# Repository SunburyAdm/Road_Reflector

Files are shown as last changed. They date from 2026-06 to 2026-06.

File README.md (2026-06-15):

# Smart Road Reflectors — Road Condition Monitoring & Data API Platform

Alpha Prototype of a Smart Road Reflector system that collects road condition
data, detects vehicle-related vibration events, transmits sensor data over a
LoRaWAN network, and exposes processed information through a cloud-based API,
dashboard, and 3D visualization.

## Repository Structure

```
.
├── docs/                     Project proposal, architecture, API, phases, budget
│
├── 01-device-layer/          Smart Road Reflector node
│   ├── firmware/             Production LoRaWAN firmware (RAK4631 / nRF52840)
│   ├── hardware/             Hardware design, recommended stack, placement
│   └── prototype-esp32c3/    Current ESP32-C3 bench prototype (sensor validation)
│
├── 02-connectivity-layer/    LoRaWAN network + outdoor gateway
│   ├── lorawan/
│   └── gateway/
│
├── 03-cloud-platform/        Ingestion, processing, storage, analytics
│   ├── chirpstack/           LoRaWAN Network Server
│   ├── mqtt-broker/          Mosquitto MQTT
│   ├── backend-fastapi/      FastAPI services
│   └── databases/            PostgreSQL + InfluxDB/TimescaleDB
│
├── 04-api-layer/             REST API, streaming API, auth, documentation
│
├── 05-data-consumers/        Visualization & consumer-facing layers
│   ├── web-dashboard/
│   ├── 3d-visualization/     Three.js
│   └── grafana/
│
└── tools/                    Helper scripts (live serial plotter, etc.)
```

## Documentation Index

| Document | Description |
|---|---|
| [docs/01-project-proposal.md](docs/01-project-proposal.md) | Full Alpha Prototype proposal |
| [docs/02-architecture.md](docs/02-architecture.md) | 5-layer system architecture |
| [docs/03-api-design.md](docs/03-api-design.md) | API groups, endpoints, payloads |
| [docs/04-development-phases.md](docs/04-development-phases.md) | Phases 1–7 and Alpha scope |
| [docs/05-budget.md](docs/05-budget.md) | Estimated prototype budget |

## Architecture Layers

```
1. Device Layer       → Smart Road Reflector nodes with embedded sensors
2. Connectivity Layer → LoRaWAN network and outdoor gateway
3. Cloud Platform     → Ingestion, processing, validation, storage, analytics
4. API Layer          → REST API, streaming API, authentication, docs
5. Data Consumers     → Dashboard, agencies, fleets, insurers, ADAS/OEM users
```

## Technology Stack

```
Device        : RAK4631 / nRF52840 + SX1262, ADXL362, SHT31, water/tilt/piezo, LiFePO₄ + solar
Connectivity  : LoRaWAN US915, RAK7289V2 / Milesight UG67 gateway
Network Server: ChirpStack
Messaging     : Mosquitto MQTT
Backend       : FastAPI
Databases     : PostgreSQL + InfluxDB / TimescaleDB
Dashboard     : Grafana + custom web dashboard
3D            : Three.js
Docs          : OpenAPI / Swagger
Security      : LoRaWAN OTAA, API keys, JWT, HTTPS
```

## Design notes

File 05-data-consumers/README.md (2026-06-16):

# 05 — Data Consumers

Visualization and consumer-facing layers.

## Structure

```
05-data-consumers/
├── web-dashboard/      Custom technical web dashboard
│   ├── index.html      Dashboard shell (KPIs, panels, 3D mount)
│   ├── css/dashboard.css
│   └── js/dashboard.js Hydration + live WebSocket controller
├── 3d-visualization/   Three.js real-time 3D road visualization
│   └── js/scene.js     SiteScene: builds site model, animates vehicles/pulses
└── grafana/            Grafana dashboards
```

> The dashboard and 3D scene are served by the FastAPI backend as static files at
> `http://localhost:8000/` (the dashboard imports `scene.js` from the sibling
> `3d-visualization/` folder). See [`../03-cloud-platform/DEMO.md`](../03-cloud-platform/DEMO.md)
> for the full run flow.

## Technical Dashboard

```
- Sensor location map
- Device online/offline status
- Battery level / solar charging status
- Pavement temperature / humidity / surface water
- Vibration levels / tilt or movement alerts
- Communication quality
- Historical trends
- Active alerts
- Exportable reports
```

## 3D Road Visualization (Three.js)

```
- Road segment model
- Smart reflectors installed on the road
- Real-time vehicle events
- Vehicle size approximation
- Vibration waves around sensors
- Road condition color indicators
- Live sensor values
- Alerts and event markers
```

Connected to the backend through WebSocket events (`WS /v1/stream/events`).

## Consumers

Government agencies, road maintenance companies, insurance companies, fleet and
logistics operators, universities and research labs, OEM / ADAS / autonomous
vehicle teams.

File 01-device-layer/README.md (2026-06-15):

# 01 — Device Layer

Smart Road Reflector node: embedded electronics, firmware, and hardware design.

## Structure

```
01-device-layer/
├── firmware/            Production LoRaWAN firmware (RAK4631 / nRF52840 + SX1262)
├── hardware/            Hardware design, recommended stack, bring-up notes
└── prototype-esp32c3/   Current ESP32-C3 bench prototype (sensor validation)
```

## Core Hardware Target

```
MCU + LoRaWAN : RAK4631 / nRF52840 + SX1262
Accelerometer : ADXL362 (low-power IMU)
Temp/Humidity : SHT31 + pavement temperature sensor
Other sensors : surface water sensor, tilt detection, optional piezo impact
Power         : LiFePO₄ battery + solar panel + solar charging + regulator
```

## Measured Signals

Vibration / acceleration, pavement temperature, internal humidity, surface
water presence, tilt / displacement, impact intensity, battery voltage, solar
charging voltage, communication signal quality.

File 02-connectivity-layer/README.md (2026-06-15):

# 02 — Connectivity Layer

LoRaWAN network and outdoor gateway configuration.

## Structure

```
02-connectivity-layer/
├── lorawan/   LoRaWAN US915 plan, OTAA keys policy, payload decoders
└── gateway/   Outdoor gateway configuration
```

## Recommended Setup

```
- LoRaWAN US915 frequency plan
- Outdoor LoRaWAN gateway
- Secure device registration
- OTAA device activation
- MQTT integration with backend services
```

## Gateway Options

```
Option A: RAK7289V2 Outdoor LoRaWAN Gateway
Option B: Milesight UG67 Outdoor LoRaWAN Gateway
```

The gateway receives data from multiple smart reflectors and forwards the
payloads to the cloud platform.

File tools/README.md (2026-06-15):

# Tools

Helper scripts for prototype development and sensor data analysis.

## Live serial plotter

```
python plot_sensors_live.py --port COM6 --baud 115200
```

Plots live sensor data streamed from the ESP32-C3 bench prototype.

> Prototype firmware: [`../01-device-layer/prototype-esp32c3/`](../01-device-layer/prototype-esp32c3/).

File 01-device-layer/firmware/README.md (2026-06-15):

# Firmware

Production firmware for the Smart Road Reflector node.

Target platform: **RAK4631 / nRF52840 + SX1262** with LoRaWAN US915 (OTAA).

## Planned responsibilities (Phase 4 / Phase 5)
- Sensor sampling (accelerometer, temperature, humidity, water, tilt)
- Vibration event detection
- Battery and solar charging monitoring
- LoRaWAN OTAA activation and uplink scheduling
- Compact telemetry payload encoding

> The current sensor-validation code runs on an ESP32-C3 bench prototype.
> See [`../prototype-esp32c3/`](../prototype-esp32c3/).

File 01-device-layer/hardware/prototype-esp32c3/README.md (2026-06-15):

# ESP32-C3 Bench Prototype

Current sensor-validation prototype running on an ESP32-C3. Used to validate the
thermistor (pavement temperature) and LIS3DH accelerometer (vibration) before
moving to the production RAK4631 / nRF52840 hardware.

## Sketches

| Folder | Description |
|---|---|
| `Road_Reflector/` | Main reflector sketch |
| `Road_Reflector_Temperature/` | Temperature-focused sketch |
| `thermistor_and_lis3dh_2/` | Thermistor + LIS3DH combined test (with serial debug reader) |

> Live serial plotting tooling lives in [`../../tools/`](../../tools/).

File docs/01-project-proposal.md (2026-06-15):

# Smart Road Reflectors — Road Condition Monitoring & Data API Platform

## Alpha Prototype Project Proposal

## 1. Project Overview
The goal of this project is to develop an Alpha Prototype of a Smart Road Reflector system capable of collecting road condition data, detecting vehicle-related vibration events, transmitting sensor data through a low-power wireless network, and exposing the processed information through a cloud-based API and dashboard.

The system will be designed as an infrastructure intelligence platform for roads, highways, industrial facilities, smart cities, insurance companies, logistics fleets, research institutions, and future autonomous vehicle ecosystems.

This prototype will not be a simple low-cost proof of concept. It will be built as a near-commercial demonstration platform with real sensor nodes, LoRaWAN communication, a gateway, backend services, API documentation, real-time visualization, and a dashboard.

---

## 2. Project Objective
The main objective is to create a functional Smart Road Reflector platform that can:

- Monitor vibration and acceleration from road traffic.
- Measure pavement temperature.
- Detect humidity or possible surface water.
- Monitor reflector movement, tilt, or displacement.
- Estimate vehicle events using multiple sensors.
- Approximate vehicle speed, direction, size class, and axle count.
- Send data through a LoRaWAN network.
- Store sensor and event data in a cloud platform.
- Provide a REST API and real-time streaming API.
- Display road condition data in a dashboard and 3D road visualization.

---

## 3. System Architecture
The proposed architecture is divided into five main layers:

```
1. Device Layer
   Smart Road Reflector nodes with embedded sensors

2. Connectivity Layer
   LoRaWAN network and outdoor gateway

3. Cloud Platform
   Data ingestion, processing, validation, storage, and analytics

4. API Layer
   REST API, streaming API, authentication, and documentation

5. Data Consumers
   Dashboard, government agencies, maintenance companies, fleets, insurers, universities, and ADAS/OEM users
```

See [02-architecture.md](02-architecture.md) for the detailed layer breakdown.

---

## 15. Estimated Prototype Budget
A realistic Alpha Prototype budget range is:

```
Estimated total hardware and infrastructure budget:
$2,500 to $8,000 USD
```

See [05-budget.md](05-budget.md) for the full breakdown.

---

## 16. Expected Outcome
At the end of the Alpha Prototype, the project should demonstrate a functional smart road intelligence platform capable of:

- Collecting sensor data from road-mounted reflectors
- Transmitting data through LoRaWAN
- Processing and storing road condition telemetry
- Detecting vehicle vibration events
- Estimating vehicle class and speed
- Displaying real-time sensor values
- Providing API access to external consumers
- Showing road and vehicle events in a 3D visualization

The prototype will be suitable for demonstrations with government agencies, road maintenance companies, insurance companies, fleet and logistics operators, universities and research labs, and OEM / ADAS / autonomous vehicle teams.

---

## 17. Final Project Definition
This project will create an Alpha Prototype of a Smart Road Reflector Road Condition Monitoring and Data API Platform.

The system combines embedded sensing, LoRaWAN communication, cloud processing, API services, and visualization tools to transform passive road reflectors into active infrastructure intelligence nodes.

The Alpha Prototype will validate the technical feasibility of using smart reflectors to monitor road conditions, detect vehicle events, estimate vehicle size classes, and provide real-time road data through a scalable API platform.

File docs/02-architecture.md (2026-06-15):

# System Architecture

The platform is divided into five main layers. Each layer maps to a top-level
folder in this repository.

| Layer | Folder | Responsibility |
|---|---|---|
| 1. Device Layer | [`01-device-layer/`](../01-device-layer/) | Smart Road Reflector nodes with embedded sensors |
| 2. Connectivity Layer | [`02-connectivity-layer/`](../02-connectivity-layer/) | LoRaWAN network and outdoor gateway |
| 3. Cloud Platform | [`03-cloud-platform/`](../03-cloud-platform/) | Ingestion, processing, validation, storage, analytics |
| 4. API Layer | [`04-api-layer/`](../04-api-layer/) | REST API, streaming API, authentication, documentation |
| 5. Data Consumers | [`05-data-consumers/`](../05-data-consumers/) | Dashboard, agencies, fleets, insurers, ADAS/OEM users |

---

## 4. Device Layer — Smart Road Reflector Node

### Core Hardware

```
MCU + LoRaWAN:
- RAK4631 / nRF52840 + SX1262 LoRa module

Main sensors:
- Low-power accelerometer / IMU
- Pavement temperature sensor
- Internal temperature and humidity sensor
- Surface water detection sensor
- Tilt / movement detection
- Optional piezo impact sensor

Power system:
- LiFePO₄ rechargeable battery
- Solar panel
- Solar charging circuit
- High-efficiency power regulator

Mechanical:
- Low-profile reflector enclosure
- Weather-resistant sealing
- Road-safe housing
- Replaceable or serviceable electronics module
```

### Sensor Capabilities

```
- Vibration / acceleration
- Pavement temperature
- Internal humidity
- Surface water presence
- Tilt or displacement
- Impact intensity
- Battery voltage
- Solar charging voltage
- Communication signal quality
```

---

## 5. Connectivity Layer

```
- LoRaWAN US915 frequency plan
- Outdoor LoRaWAN gateway
- Secure device registration
- OTAA device activation
- MQTT integration with backend services
```

### Gateway Options

```
Option A: RAK7289V2 Outdoor LoRaWAN Gateway
Option B: Milesight UG67 Outdoor LoRaWAN Gateway
```

---

## 6. Cloud Platform — Recommended Software Stack

```
LoRaWAN Network Server : ChirpStack
Message Broker         : Mosquitto MQTT
Backend API            : FastAPI
Relational Database    : PostgreSQL
Time-Series Database   : InfluxDB or TimescaleDB
Dashboard              : Grafana + custom web dashboard
3D Visualization       : Three.js
Documentation          : OpenAPI / Swagger
```

---

## 10. Vehicle Detection Method

Multiple reflectors installed along a lane estimate vehicle movement by
comparing vibration arrival times.

```
Traffic Direction →

S1 -------- 4 m -------- S2 -------- 4 m -------- S3
```

Estimated outputs: direction, approximate speed, event duration, approximate
vehicle length, number of vibration peaks, possible axle count, vehicle size class.

```
speed          = distance_between_sensors / time_difference
vehicle_length = estimated_speed × event_duration
```

---

## 12. Security and Reliability

```
Device Security        : Unique device ID, unique LoRaWAN keys, OTAA, signed firmware (future)
Communication Security : LoRaWAN encryption, HTTPS for API, MQTT authentication
API Security           : API keys, JWT for dashboard, rate limiting, request logging
Platform Reliability   : DB backups, gateway monitoring, device health, cloud logs, offline alerts
```

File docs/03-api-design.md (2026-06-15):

# API Design

## 7. API Layer

The API layer exposes sensor values, road condition data, vehicle events,
alerts, and device status.

### Main API Groups

```
Device API
Telemetry API
Road Condition API
Vehicle Event API
Alert API
Streaming API
```

### Example API Endpoints

```
GET  /v1/devices
GET  /v1/devices/{device_id}
GET  /v1/devices/{device_id}/latest
GET  /v1/devices/{device_id}/readings

GET  /v1/segments
GET  /v1/segments/{segment_id}/condition
GET  /v1/segments/{segment_id}/traffic-summary

GET  /v1/vehicle-events
GET  /v1/vehicle-events/{event_id}

GET  /v1/alerts
GET  /v1/alerts/active

POST /v1/ingest/telemetry
POST /v1/ingest/vehicle-event

WS   /v1/stream/events
```

---

## 8. Example Sensor Telemetry Payload

```json
{
  "device_id": "SRR-OH-001",
  "timestamp": "2026-06-12T19:20:10.000Z",
  "battery_v": 3.42,
  "battery_pct": 78,
  "solar_v": 5.18,
  "pavement_temp_c": 31.4,
  "internal_temp_c": 29.8,
  "humidity_pct": 61.2,
  "surface_water": false,
  "tilt_deg": 1.3,
  "accel_rms": 0.084,
  "accel_peak_g": 0.36,
  "vibration_energy": 12.7,
  "rssi": -105,
  "snr": 7.4
}
```

---

## 9. Example Vehicle Event Payload

```json
{
  "vehicle_event_id": "VEH-000482",
  "segment_id": "OH-TEST-001",
  "lane": 1,
  "timestamp": "2026-06-12T19:20:11.240Z",
  "sensor_ids": [
    "SRR-OH-001",
    "SRR-OH-002",
    "SRR-OH-003"
  ],
  "estimated_speed_kmh": 72.4,
  "estimated_length_m": 4.9,
  "estimated_axles": 2,
  "vehicle_class": "large_vehicle",
  "confidence": 0.84
}
```

### Initial Vehicle Classes

```
- small_vehicle
- medium_vehicle
- large_vehicle
- heavy_vehicle
- unknown
```

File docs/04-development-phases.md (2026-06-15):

# Development Phases

## Phase 1 — System Design and Architecture
Deliverables:
```
- System architecture document
- Hardware block diagram
- API design
- Database schema
- Communication payload definition
- Dashboard wireframe
```
Estimated duration: 2 to 3 weeks

---

## Phase 2 — Cloud Platform and API Prototype
Deliverables:
```
- FastAPI backend
- PostgreSQL database
- InfluxDB or TimescaleDB integration
- MQTT broker
- OpenAPI documentation
- Simulated sensor data ingestion
- Basic REST API
- WebSocket event stream
```
Estimated duration: 3 to 5 weeks

---

## Phase 3 — Dashboard and 3D Visualization
Deliverables:
```
- Web dashboard
- Sensor map
- Device status panel
- Road condition charts
- Alert list
- 3D road visualization
- Real-time vehicle event display
```
Estimated duration: 4 to 6 weeks

---

## Phase 4 — Smart Reflector Hardware Prototype
Deliverables:
```
- Electronics design
- Sensor integration
- Power system prototype
- LoRaWAN firmware
- Battery monitoring
- Solar charging test
- Vibration event detection firmware
- Enclosure prototype
```
Estimated duration: 6 to 10 weeks

---

## Phase 5 — Gateway and LoRaWAN Integration
Deliverables:
```
- Outdoor gateway configuration
- ChirpStack setup
- Device registration
- LoRaWAN payload decoder
- MQTT integration
- End-to-end telemetry test
```
Estimated duration: 2 to 4 weeks

---

## Phase 6 — Controlled Road Test
Deliverables:
```
- Installation of 6 smart reflector nodes
- Controlled vehicle pass tests
- Sensor calibration
- Vehicle event dataset
- Speed and size estimation validation
- Battery and solar performance report
```
Estimated duration: 4 to 6 weeks

---

## Phase 7 — Alpha Demonstration Platform
Deliverables:
```
- Final Alpha dashboard
- API documentation portal
- Live road condition monitoring
- Real-time vehicle event visualization
- Demo dataset
- Technical report
- Investor/customer demo package
```
Estimated duration: 2 to 4 weeks

---

## 13. Alpha Prototype Scope

```
- 6 smart road reflector nodes
- 1 outdoor LoRaWAN gateway
- 1 cloud server
- LoRaWAN network server
- MQTT broker
- Backend API
- Time-series database
- Dashboard
- 3D visualization
- OpenAPI documentation
```

### Suggested Physical Deployment

```
Lane 1:  S1 ---- 4 m ---- S2 ---- 4 m ---- S3
Lane 2:  S4 ---- 4 m ---- S5 ---- 4 m ---- S6
```

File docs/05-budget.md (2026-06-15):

# Estimated Prototype Budget

A realistic Alpha Prototype budget range:

```
Estimated total hardware and infrastructure budget:
$2,500 to $8,000 USD
```

## Estimated Breakdown

| Item | Estimated Cost |
|---|---|
| 6 smart reflector prototypes | $600 to $1,800 |
| Outdoor LoRaWAN gateway | $400 to $900 |
| Solar, battery, enclosure, mechanical parts | $600 to $2,000 |
| PCB prototype and assembly | $500 to $2,000 |
| Cloud server and services | $30 to $250 per month |
| Testing materials and installation | $300 to $1,000 |

> This estimate does not include engineering labor, certification, final
> tooling, mass production, or legal/patent review.

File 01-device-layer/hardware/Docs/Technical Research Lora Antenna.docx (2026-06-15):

Technical Research: Near-Ground LoRa Antenna for a Smart Road Reflector

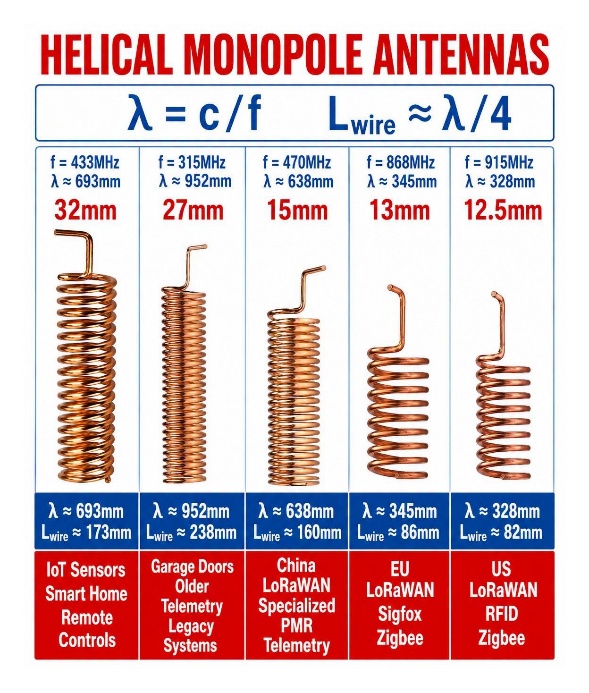
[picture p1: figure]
Puede ser una imagen de texto que dice "f= 433MHz እ= 693mm 32mm HELICAL MONOPOLE ANTENNAS እ=/ Lwire እ/4 470MHz f=868MHz f= እ= 638mm እ= 345mm 15mm 13mm f=315MHz እ= 952mm 27mm f=915MHz ለ= 328mm 12.5mm 12. እ 693mm Lwire 173mm ለ 952mm Lwire 238mm እ 638mm Lwire 160mm እ= 345mm Lwire 86mm loT Sensors Sma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

1. Executive Summary

Designing a LoRa antenna for a device installed almost flush with the ground is possible, but it is a difficult RF problem. A near-ground antenna will suffer from reduced efficiency, shorter communication range, detuning, signal absorption, and high sensitivity to moisture, snow, salt, vehicles, and pavement material.

The main conclusion is:

The best solution is not a completely flat antenna, but a low-profile antenna that appears flush from the outside while keeping a small vertical RF structure inside the reflector.

The recommended prototype design is:

915 MHz vertical helical antenna

Height: 25–35 mm

Diameter: 5–8 mm

Ground plane: 70–100 mm if the reflector body allows it

Matching network: π-network

Housing: sealed non-metallic plastic

Gateway: elevated, ideally 3–10 m or higher

For testing in Ohio / United States, the target LoRaWAN band should be US902–928 MHz, with a practical center frequency around 915 MHz.

2. Engineering Problem

The goal is to design a LoRa antenna for a road-installed device, likely inside a smart road reflector, with the following constraints:

- Very low physical profile

- Installed almost flush with the road surface

- Exposure to water, snow, salt, vibration, dust, and extreme temperature

- Low-power LoRa communication

- Low manufacturing cost

- Reliable range to other reflectors or gateways

- Possible mesh or relay communication architecture

The main issue is that the road environment is a poor RF environment. Pavement, soil, concrete, water, and nearby vehicles affect antenna behavior. They can detune the antenna, absorb energy, distort the radiation pattern, and reduce range.

Antenna performance near the ground is strongly affected by:

- Height above the ground

- Pavement material

- Moisture content

- Ground plane size

- Antenna orientation

- Vehicle obstruction

- Snow, salt, and ice

- Housing material

3. Target Frequency

For LoRa in the United States, the practical design target is:

Band: US902–928 MHz

Center frequency: approximately 915 MHz

Wavelength: approximately 328 mm

Quarter wavelength: approximately 82 mm

Calculation:

λ = c / f

c = 300,000,000 m/s

f = 915,000,000 Hz

λ = 0.328 m = 328 mm

λ/4 = 82 mm

This means that a physically efficient quarter-wave antenna at 915 MHz would be about 82 mm long.

Because a road reflector cannot realistically have an 82 mm vertical whip antenna, the antenna must be electrically shortened. Practical options include:

- Helical antenna

- PIFA antenna

- Inverted-F antenna

- PCB meander antenna

- Chip antenna

- Patch antenna

4. Antenna Options

Option A — Quarter-Wave Whip / Monopole Antenna

This is electrically one of the best options.

Physical length: ~82 mm

Ideal orientation: vertical

Ground plane: required

Cost: low

RF performance: high

Physical profile: poor for road installation

A quarter-wave monopole would give good range and simple tuning, but it is not mechanically suitable for a reflector installed close to the ground.

Conclusion: good for laboratory testing, not ideal for the final product.

Option B — Vertical Helical Antenna

A helical antenna is a coiled conductor that compresses the physical size of the antenna while maintaining useful electrical length.

Physical height: 20–40 mm

Diameter: 5–10 mm

Cost: low

RF performance: medium to good

Difficulty: medium

Physical profile: acceptable

This is the best balance for your application. The antenna can be placed inside a small raised section of the reflector, protected by plastic. Visually, the product can still appear low-profile, but electrically the antenna keeps a useful vertical component.

Conclusion: best option for the first prototype.

Option C — PIFA / Inverted-F Antenna

A PIFA, or Planar Inverted-F Antenna, is commonly used in compact wireless devices.

Physical height: 3–10 mm

Cost: low to medium

RF performance: medium

Difficulty: high

Requires good ground plane

Requires careful tuning

This is a good option if the industrial design cannot allow a 25–35 mm vertical antenna volume.

Conclusion: strong second option, but more difficult to design correctly.

Option D — PCB Meander Antenna

A PCB meander antenna is printed directly on the circuit board in a folded shape.

Physical height: PCB thickness only

Cost: very low

RF performance: low to medium

Difficulty: high

Very sensitive to housing and ground plane

This option is attractive because it is cheap and flat, but it is not ideal for a harsh road environment where the antenna is close to pavement, water, salt, and metal.

Conclusion: possible, but risky for long-range communication.

Option E — Chip Antenna

A chip antenna is a compact ceramic or RF component mounted on the PCB.

Size: very small

Cost: medium

RF performance: medium to low if not tuned properly

Difficulty: medium to high

Requires strict layout rules

Chip antennas are compact, but their performance depends heavily on PCB layout, ground plane, housing, and nearby components.

Conclusion: viable only if the manufacturer’s layout guidelines are followed and the final product is tuned with a VNA.

Option F — Patch Antenna Facing Upward

A patch antenna can radiate upward, which may be useful if the gateway is mounted above the road.

Profile: low

Radiation: directional upward

Cost: medium to high

Difficulty: high

Size at 915 MHz: relatively large

This could work well if communication is mainly between the reflector and an elevated gateway. It is less ideal for reflector-to-reflector communication.

Conclusion: interesting for gateway-based architecture, less ideal for mesh between reflectors.

5. Technical Comparison

Antenna Type | Physical Profile | Cost | Expected Range | RF Robustness | Recommendation
Quarter-wave whip | Poor | Low | High | High | Lab testing only
Vertical helical | Good | Low | Medium/high | Medium | Best option
PIFA | Very good | Medium | Medium | Medium | Strong alternative
PCB meander | Excellent | Very low | Low/medium | Low | Risky
Chip antenna | Excellent | Medium | Medium | Medium/low | Viable with tuning
Patch antenna | Good | Medium/high | Medium/high upward | Medium | Good for elevated gateway

6. Recommended Design

6.1 Physical Architecture

Non-metallic plastic cover

┌───────────────────────────────┐

│ 915 MHz helical antenna │

│ 25–35 mm high │

└──────────────┬────────────────┘

│

π matching network

│

LoRa module

│

PCB/base ground plane

│

Battery + sensors

│

Sealed road housing

6.2 Initial Prototype Specification

Target frequency: 915 MHz

Operating band: 902–928 MHz

Antenna type: loaded helical monopole

Physical height: 25–35 mm

Coil diameter: 5–8 mm

Approximate conductor length: 75–85 mm

Target impedance: 50 Ω

Target return loss: < -10 dB

Target VSWR: < 2:1

Minimum ground plane: 70 mm

Preferred ground plane: 100 mm or larger

Housing material: ABS, polycarbonate, nylon, or RF-friendly plastic

Avoid: metal, metallic paint, carbon fiber, screws near the antenna

7. Concept Diagram

Side View

Elevated Gateway

▲

│

│ LoRa link

│

┌────────┴────────┐

│ │

│ main RF │

│ radiation │

│ │

──────────────────────────────── road surface

┌───────────────────┐

│ smart reflector │

│ ┌─────┐ │

│ │coil │ │ ← vertical helical antenna

│ └──┬──┘ │

│ │ │

│ matching + RF │

│───────────────────│ ← ground plane

│ battery/sensors │

└───────────────────┘

8. Why a Completely Flat Antenna Is Not Recommended

A completely flat antenna installed at road level has three major problems.

8.1 Pavement Loss

Concrete, asphalt, wet soil, water, and road salt act as lossy dielectric materials. They can absorb RF energy and shift the antenna away from its tuned frequency.

8.2 Distorted Radiation Pattern

A near-ground antenna does not radiate cleanly. Energy can couple into the road surface, reflect unpredictably, or be blocked by vehicles.

8.3 Polarization Loss

Most LoRa gateways use vertically polarized antennas. If the reflector antenna is horizontal, the link can suffer additional polarization mismatch loss.

For this reason, even a small vertical antenna element is valuable.

9. Link Budget Considerations

LoRa has a strong link budget compared with many wireless technologies, but the road environment can consume a large part of that margin.

A simplified estimate:

TX power: up to +22 dBm, depending on module and regulatory limits

Receiver sensitivity: approximately -137 to -148 dBm depending on LoRa settings

Reflector antenna gain: possibly -5 to -15 dBi if very low-profile

Gateway antenna gain: +2 to +6 dBi

Housing / pavement / moisture losses: 3–15 dB or more

The system may still work because LoRa is robust, but range will depend heavily on:

- Gateway height

- Antenna height inside the reflector

- Pavement material

- Moisture, snow, and salt

- Vehicle obstruction

- Spreading factor

- Transmit power

- Antenna matching quality

- Ground plane size

In practice, increasing gateway height will likely improve performance more than simply increasing transmit power.

10. Regulatory Considerations

For the United States, LoRa operation around 902–928 MHz falls under FCC Part 15 rules. For a commercial product, this means:

- Use a compliant LoRa module or certify the final product.

- Do not assume any antenna can be used with a pre-certified module.

- Check the antenna types allowed by the module certification.

- Avoid high-gain antennas unless the transmit power is adjusted accordingly.

- Keep documentation of the final antenna, matching network, and enclosure.

For the reflector itself, a low-gain omnidirectional antenna is preferable.

11. Recommended Test Plan

Phase 1 — Bench Antenna Test

Goal: find an antenna that resonates correctly around 915 MHz.

Tools:

- VNA, such as NanoVNA V2 or better

- U.FL or SMA test connector

- Prototype ground plane

- Test housing or 3D-printed enclosure

Measurements:

- S11

- VSWR

- Resonant frequency

- Bandwidth

- Effect of housing

Minimum target:

Return loss < -10 dB across 902–928 MHz

VSWR < 2:1

Phase 2 — Reflector Integration Test

Measure the antenna under realistic conditions:

1. Reflector open

2. Reflector closed

3. Reflector on a table

4. Reflector on concrete

5. Reflector on asphalt

6. Reflector with water on top

7. Reflector with salt / ice exposure

8. Reflector near metal

The most important thing is to check frequency shift. If the antenna resonates at 915 MHz on the bench but shifts to 880 MHz or 950 MHz after being installed in the housing, the design is not ready.

Phase 3 — Field Test

Record the following variables:

- RSSI

- SNR

- Packet loss

- Spreading factor

- Distance

- Gateway height

- Reflector orientation

- Weather condition

- Vehicle presence

Suggested distances:

- 10 m

- 50 m

- 100 m

- 250 m

- 500 m

- 1 km

Critical tests:

- Gateway at 1 m height

- Gateway at 3 m height

- Gateway at 6 m height

- Gateway at 10 m height

Expected result:

A higher gateway will likely improve the link more than increasing the reflector transmit power.

12. Prototype Proposals

Prototype A — Vertical Helical Antenna

Type: 915 MHz helical antenna

Height: 30 mm

Diameter: 6 mm

Ground plane: 80–100 mm

Matching: π-network

Purpose: main prototype

Advantages:

Best balance of size, cost, and range.

Disadvantages:

Requires a small vertical RF chamber inside the reflector.

Prototype B — Internal PIFA

Type: PIFA / IFA

Height: 5–10 mm

Dedicated PCB region

Integrated ground plane

Mandatory matching

Purpose: flatter alternative

Advantages:

More compatible with a nearly flush mechanical design.

Disadvantages:

Harder to design and tune correctly.

Prototype C — PCB Meander Antenna

Type: printed PCB antenna

Height: PCB thickness only

Cost: very low

Purpose: minimum-profile experiment

Advantages:

Very low cost and very flat.

Disadvantages:

Likely shorter range and more sensitivity to the environment.

13. Final Recommendation

For a LoRa smart road reflector installed almost flush with the ground, the recommended technical solution is:

Use a 915 MHz vertical helical antenna,

sealed inside a non-metallic plastic cover,

with a dedicated ground plane,

a π matching network,

and an elevated gateway.

A completely flat antenna should only be used if the required range is short or if many gateways are installed nearby.

The best interpretation of “almost flush with the ground” is:

The product should look flush from the outside, but internally it should include a small 25–35 mm RF chamber for the antenna.

This design has the best chance of being robust, low-cost, manufacturable, and effective in real road conditions.

Investigación técnica: Antena LoRa prácticamente al ras del suelo para reflector vial inteligente

1. Resumen ejecutivo

Para un sistema de smart road reflectors con LoRa, la antena es uno de los puntos más críticos. Una antena colocada al ras del suelo puede funcionar, pero tendrá menor eficiencia, menor alcance y mayor variación de desempeño por humedad, nieve, sal, concreto, asfalto, vehículos y orientación.

La conclusión principal es:

La mejor solución no es una antena completamente plana, sino una antena de bajo perfil que se vea al ras visualmente, pero que mantenga una pequeña estructura vertical interna de 20–40 mm dentro del reflector.

La opción más recomendable para prototipo es:

Antena helicoidal vertical 915 MHz

Altura: 25–35 mm

Diámetro: 5–8 mm

Plano de tierra: 70–100 mm si el housing lo permite

Red de matching: π-network

Housing: plástico no metálico, sellado

Gateway: elevado, idealmente 3–10 m o más

Para Ohio / Estados Unidos, la banda LoRaWAN usada normalmente es US902–928 MHz. The Things Network resume esta banda como 902–928 MHz, con canales uplink de 902.3–914.9 MHz y downlink de 923.3–927.5 MHz. (The Things Network (https://www.thethingsnetwork.org/docs/lorawan/regional-parameters/us915/))

2. Problema de ingeniería

El objetivo es diseñar una antena LoRa para un dispositivo instalado en carretera, posiblemente dentro de un reflector vial, con estas restricciones:

- Muy bajo perfil físico.

- Instalación prácticamente al ras del suelo.

- Exposición a agua, nieve, sal, vibración, polvo y temperatura extrema.

- Comunicación LoRa de bajo consumo.

- Bajo costo de fabricación.

- Buen alcance hacia otros reflectores o gateways.

- Posible red mesh o comunicación hacia concentrador.

El problema principal es que la carretera es un mal entorno RF. El suelo modifica el patrón de radiación, cambia la impedancia de la antena y absorbe parte de la energía. En estudios recientes de antenas tipo monopolo cerca de suelo/humedad, se reportó que la altura del dispositivo y el contenido de agua del suelo afectan impedancia, ancho de banda, patrón de radiación y eficiencia; en el peor escenario, la eficiencia de radiación cayó hasta 44%. (MDPI (https://www.mdpi.com/2079-9292/14/3/544))

3. Frecuencia objetivo

Para Estados Unidos:

Banda: US902–928 MHz

Frecuencia central práctica: 915 MHz

Longitud de onda aproximada: 328 mm

Cuarto de onda: 82 mm

Cálculo:

λ = c / f

c = 300,000,000 m/s

f = 915,000,000 Hz

λ = 0.328 m = 328 mm

λ/4 = 82 mm

Esto significa que una antena eficiente de 1/4 de onda para 915 MHz tendría aproximadamente 82 mm de longitud eléctrica. Como el reflector vial no puede tener una varilla vertical de 82 mm, se necesita una antena compactada: helicoidal, PIFA, IFA, chip antenna o PCB meander.

4. Revisión de alternativas de antena

Opción A — Antena whip / monopolo de 1/4 de onda

Es la opción eléctricamente más simple y eficiente.

Longitud física: ~82 mm

Orientación ideal: vertical

Plano de tierra: necesario

Costo: bajo

Desempeño: alto

Perfil físico: malo para carretera

Semtech describe la antena externa de cuarto de onda como una de las mejores desde el punto de vista de sensibilidad y ganancia para 915 MHz, pero también indica que ocupa más espacio y aumenta costo por requerir conector externo.

Conclusión: buena para pruebas de laboratorio, mala para producto final al ras del suelo.

Opción B — Antena helicoidal vertical

Una antena helicoidal es básicamente una longitud de conductor enrollada. Permite reducir el tamaño físico manteniendo una longitud eléctrica útil. Semtech la presenta como una alternativa de bajo costo frente a chip antennas; también advierte que tiene ancho de banda estrecho y puede detunarse por objetos cercanos en el PCB.

Altura física: 20–40 mm

Diámetro: 5–10 mm

Costo: bajo

Desempeño: medio/bueno

Dificultad: media

Perfil físico: aceptable

Conclusión: es la opción más balanceada para tu caso.

Esta antena podría ir dentro de una pequeña zona elevada del reflector, sin que parezca una antena externa.

Opción C — PIFA / Inverted-F Antenna

La PIFA es una antena de bajo perfil usada en muchos dispositivos compactos.

Altura física: 3–10 mm

Costo: bajo/medio

Desempeño: medio

Dificultad: alta

Requiere buen plano de tierra

Requiere tuning cuidadoso

Conclusión: buena si el diseño industrial no permite ninguna altura vertical, pero requiere más ingeniería RF que una helicoidal.

Opción D — PCB meander antenna

Es una antena impresa en el PCB, doblada en forma de serpentina para reducir espacio.

Altura física: ~1.6 mm del PCB

Costo: muy bajo

Desempeño: bajo/medio

Dificultad: alta

Muy sensible al housing y al plano de tierra

Semtech indica que las antenas PCB pueden funcionar bien si hay suficiente espacio, pero que longitud, ancho, espesor del cobre y tamaño/forma del plano de tierra afectan la eficiencia y el patrón de radiación.

Conclusión: viable para prototipo compacto, pero no sería mi primera opción para una carretera si necesitas rango confiable.

Opción E — Chip antenna

Es una antena cerámica/comercial compacta.

Tamaño: muy pequeño

Costo: medio

Desempeño: medio/bajo si no se sintoniza bien

Dificultad: media/alta

Requiere seguir layout del fabricante

Semtech señala que las especificaciones de chip antennas se basan en placas de prueba específicas; si el PCB real es diferente, se necesita matching para alcanzar el desempeño publicado.

Conclusión: compacta, pero riesgosa si el reflector tiene forma, batería, tornillos o materiales que detunen la antena.

Opción F — Patch antenna orientada hacia arriba

Una patch antenna puede radiar hacia arriba, lo cual tiene sentido si el gateway está elevado.

Perfil: bajo

Radiación: direccional hacia arriba

Costo: medio

Dificultad: alta

Tamaño a 915 MHz: relativamente grande

Conclusión: interesante si el sistema se comunica principalmente con gateways elevados, no tanto para comunicación reflector-a-reflector.

5. Comparación técnica

Antena | Perfil físico | Costo | Alcance esperado | Robustez RF | Recomendación
Whip 1/4 onda | Malo | Bajo | Alto | Alta | Solo laboratorio
Helicoidal vertical | Bueno | Bajo | Medio/alto | Media | Mejor opción
PIFA | Muy bueno | Medio | Medio | Media | Segunda opción
PCB meander | Excelente | Muy bajo | Bajo/medio | Baja | Riesgosa
Chip antenna | Excelente | Medio | Medio | Media/baja | Viable con tuning
Patch | Bueno | Medio/alto | Medio/alto hacia arriba | Media | Para gateway elevado

6. Diseño recomendado

6.1 Arquitectura física

Cubierta plástica / policarbonato

┌───────────────────────────────┐

│ Antena helicoidal │

│ vertical 915 MHz │

│ 25–35 mm │

└──────────────┬────────────────┘

│

Matching π

│

Módulo LoRa

│

Plano de tierra PCB/base

│

Batería + sensores

│

Base sellada IP67+

6.2 Especificación inicial

Frecuencia objetivo: 915 MHz

Banda útil: 902–928 MHz

Tipo: monopolo helicoidal cargado

Altura física: 25–35 mm

Diámetro de bobina: 5–8 mm

Longitud eléctrica del conductor: 75–85 mm

Impedancia objetivo: 50 Ω

Return loss objetivo: < -10 dB

VSWR objetivo: < 2:1

Plano de tierra mínimo: 70 mm

Plano de tierra ideal: 100 mm o más

Material del housing: ABS, PC, nylon o material plástico RF-friendly

Evitar: metal, pintura metálica, fibra de carbono, tornillos cerca de la antena

7. Diagrama del concepto

Vista lateral simplificada

Gateway elevado

▲

│

│ enlace LoRa

│

┌────────┴────────┐

│ │

│ radiación │

│ principal │

│ │

──────────────────────────────── carretera

┌───────────────────┐

│ reflector vial │

│ ┌─────┐ │

│ │coil │ │ ← antena helicoidal vertical

│ └──┬──┘ │

│ │ │

│ matching + RF │

│───────────────────│ ← plano de tierra

│ batería/sensores │

└───────────────────┘

8. Por qué no conviene una antena totalmente plana

Una antena completamente plana al ras tiene tres problemas:

8.1 Pérdida por el pavimento

El concreto, el asfalto húmedo, la tierra y el agua cercana actúan como materiales dieléctricos y parcialmente conductivos. Esto cambia la impedancia de la antena y puede absorber energía.

8.2 Patrón de radiación deformado

La antena deja de radiar de manera limpia. Parte de la energía se acopla al suelo y otra parte se refleja. En una carretera, además, vehículos grandes pueden bloquear o reflejar la señal.

8.3 Polarización incorrecta

La mayoría de gateways LoRa usan antenas verticales. Si el reflector usa una antena horizontal, puede haber pérdida por desalineación de polarización. Para comunicación hacia gateway elevado, conviene mantener componente vertical.

9. Impacto en link budget

Semtech indica que el SX1262 puede transmitir hasta +22 dBm y que su sensibilidad puede llegar hasta -148 dBm, con link budget máximo anunciado de 170 dB. (Semtech (https://www.semtech.com/products/wireless-rf/lora-connect/sx1262))

En teoría, eso da bastante margen. Pero en tu aplicación no debes diseñar usando solo el máximo teórico, porque el entorno de carretera puede agregar pérdidas considerables.

Estimación simplificada:

TX power: +22 dBm

Sensibilidad RX: -137 a -148 dBm, según configuración

Antena del reflector: -5 a -15 dBi estimado si está muy baja

Antena gateway: +2 a +6 dBi

Pérdidas por suelo/housing/humedad: 3–15 dB o más

La conclusión es que LoRa puede seguir funcionando, pero el sistema dependerá mucho de:

- altura del gateway

- altura efectiva de la antena en el reflector

- humedad/nieve/sal

- inclinación del reflector

- tráfico vehicular

- densidad de nodos

- spreading factor

- potencia de transmisión

- calidad del matching

10. Consideraciones regulatorias

Para Estados Unidos, los dispositivos en 902–928 MHz operan bajo reglas FCC Part 15.247. La regulación permite sistemas de modulación digital en 902–928 MHz con límite de potencia conducida de 1 W, y ese límite está basado en antenas con ganancia direccional no mayor a 6 dBi; si se usan antenas con ganancia mayor, se debe reducir la potencia conducida. (eCFR (https://www.ecfr.gov/current/title-47/chapter-I/subchapter-A/part-15/subpart-C/subject-group-ECFR2f2e5828339709e/section-15.247))

Para tu producto esto implica:

- No usar antenas de alta ganancia en el reflector.

- Mantener antena omnidireccional o de baja ganancia.

- Documentar antena usada si se certifica el producto.

- Si usas módulo pre-certificado, no cambiar antena sin revisar condiciones de certificación.

11. Diseño de pruebas recomendado

Fase 1 — Prueba de antena en banco

Objetivo: encontrar una antena que resuene cerca de 915 MHz.

Herramientas:

- VNA: NanoVNA V2 o mejor

- Adaptador U.FL/SMA

- Plano de tierra de prueba

- Housing impreso 3D o prototipo real

Mediciones:

- S11

- VSWR

- frecuencia de resonancia

- ancho de banda

- efecto del housing

Criterio mínimo:

Return loss < -10 dB entre 902–928 MHz

VSWR < 2:1

Fase 2 — Prueba dentro del reflector

Medir la antena en estas condiciones:

1. Reflector abierto

2. Reflector cerrado

3. Reflector sobre mesa

4. Reflector sobre concreto

5. Reflector sobre asfalto

6. Reflector con agua encima

7. Reflector con sal/hielo

8. Reflector cerca de metal

Lo importante es medir cuánto se desplaza la frecuencia. Si la antena resuena en 915 MHz en la mesa, pero al cerrar el housing se mueve a 880 MHz o 950 MHz, el diseño no sirve todavía.

Fase 3 — Prueba de campo

Variables a registrar:

- RSSI

- SNR

- packet loss

- spreading factor

- distancia

- altura del gateway

- orientación del reflector

- condición climática

- presencia de vehículos

Escenarios:

- 10 m

- 50 m

- 100 m

- 250 m

- 500 m

- 1 km

Pruebas críticas:

- gateway a 1 m de altura

- gateway a 3 m

- gateway a 6 m

- gateway a 10 m

Mi expectativa: subir el gateway será más efectivo que aumentar mucho la potencia del reflector.

12. Propuesta de prototipos

Prototipo A — Helicoidal vertical

Tipo: antena helicoidal 915 MHz

Altura: 30 mm

Diámetro: 6 mm

Plano de tierra: 80–100 mm

Matching: π-network

Uso: prototipo principal

Ventaja:

Mejor balance entre tamaño, costo y alcance.

Desventaja:

Necesita una pequeña zona vertical dentro del reflector.

Prototipo B — PIFA interna

Tipo: PIFA / IFA

Altura: 5–10 mm

PCB dedicado

Plano de tierra integrado

Matching obligatorio

Uso: alternativa más plana

Ventaja:

Más compatible con diseño al ras.

Desventaja:

Más difícil de diseñar correctamente.

Prototipo C — PCB meander

Tipo: antena impresa

Altura: solo espesor del PCB

Costo: muy bajo

Uso: prueba de mínimo perfil

Ventaja:

Muy barata.

Desventaja:

Probablemente menor alcance y más sensible al entorno.

13. Recomendación final

Para un reflector vial inteligente con LoRa, mi recomendación técnica es:

Usar una antena helicoidal vertical de 915 MHz,

encapsulada dentro de una cubierta plástica no metálica,

con plano de tierra dedicado,

red de matching π,

y gateway elevado.

No diseñaría la antena totalmente plana al ras a menos que el alcance requerido sea corto o que existan muchos gateways cercanos.

La mejor interpretación de “prácticamente al ras del suelo” sería:

Que el producto se vea al ras desde afuera, pero que internamente tenga una pequeña cámara RF elevada de 25–35 mm para la antena.

Ese diseño tiene más probabilidad de ser robusto, barato y fabricable que una antena completamente plana.

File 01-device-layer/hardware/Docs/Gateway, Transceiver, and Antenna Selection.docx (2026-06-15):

Technical Analysis: Gateway, Transceiver, and Antenna Selection for Smart Road Reflector Network

Document Reference: TA-2026-005
Project: SmartReflect Platform Integration
Subject: LoRaWAN Gateway, Node Transceiver, and Compact Antenna Selection for Smart Road Infrastructure

1. Problem Statement

The SmartReflect platform requires a reliable wireless communication architecture capable of supporting low-power road-embedded sensor nodes and bidirectional communication with a cloud-based backend. The system must transmit sensor data from each smart reflector node to the cloud and receive configuration or control commands from the cloud back to the node.

The primary engineering challenge is to select the best combination of:

- LoRaWAN gateway
- Node transceiver or LoRaWAN module
- Compact antenna
- Frequency band
- Device class
- Cloud network architecture
- RF layout strategy
- Power management strategy

The selected communication architecture must balance:

- Cost
- Range
- Power consumption
- Bidirectional communication capability
- Physical size
- Antenna integration constraints
- Low-profile housing limitations
- Ohio road deployment conditions
- Gateway availability
- Transceiver availability
- RF performance near ground level
- Scalability to multiple nodes
- Firmware complexity
- Certification and regulatory risk
- Long-term productization potential

The wireless system cannot be selected only by maximum theoretical range. In this application, the node will be installed inside a compact smart road reflector housing close to pavement level, where RF propagation is degraded by ground proximity, enclosure material, battery placement, internal electronics, and antenna size limitations.

2. System Communication Objective

The SmartReflect system is expected to operate as a distributed roadway sensing network.

The intended communication flow is:

Smart reflector node

↓

LoRaWAN uplink

↓

LoRaWAN gateway

↓

Cloud network server

↓

Application backend / analytics

↓

Optional downlink command

↓

Gateway

↓

Smart reflector node

The node must support two communication directions:

1. Uplink: Sensor data, event summaries, battery voltage, temperature, vibration features, and diagnostic information.
2. Downlink: Configuration changes, reporting interval updates, wake-up threshold changes, firmware mode changes, calibration parameters, and possible control commands.

Because the node is battery-powered and solar-assisted, downlink communication must be carefully managed to avoid excessive energy consumption.

3. Key Engineering Questions

The communication architecture must answer the following questions:

Which gateway should be used for laboratory and early field testing?

Which transceiver or LoRaWAN module should be used in the node?

Should the node use a complete LoRaWAN module or a raw SX1262 transceiver?

Which antenna type can fit inside a 125 × 125 × 25 mm road reflector housing?

How should bidirectional communication be implemented without draining the battery?

Should the node operate as LoRaWAN Class A or Class C?

How much range is realistic from a pavement-level node?

How should the antenna be placed inside the housing?

How should the PCB be designed to avoid RF detuning?

What should be selected for prototype versus final product?

4. Communication Architecture Requirements

4.1 Functional Requirements

The communication subsystem must support:

- US915 LoRaWAN operation
- Uplink sensor messages
- Downlink configuration messages
- Cloud-based processing
- Gateway packet forwarding
- Low-power node operation
- Compact antenna integration
- Multi-node scalability
- Outdoor field testing
- Local laboratory testing
- Reliable RSSI/SNR logging
- Secure device authentication

4.2 Electrical Requirements

The node radio subsystem must be compatible with:

Battery: LiFePO₄ 18650

Nominal battery voltage: 3.2 V

System rail: regulated 3.3 V

MCU: ESP32-C3 or equivalent

Power architecture: buck-boost regulated 3.3 V

Sleep-first operating strategy

The radio must tolerate:

- Short high-current transmit bursts
- Long sleep intervals
- Wake-up from deep sleep
- Downlink receive windows
- Temperature variation
- Low-voltage battery operation

4.3 Mechanical Requirements

The node antenna must fit inside a low-profile reflector housing:

Target housing footprint: approximately 125 mm × 125 mm

Maximum housing height: approximately 25 mm

Antenna must remain inside RF-transparent housing region

Antenna must be separated from battery and metal components

Antenna must survive vibration, shock, heat, and moisture

4.4 Environmental Requirements

The RF system must operate under:

- Cold Ohio winters
- Hot summer pavement conditions
- Rain and humidity
- Road salt exposure
- Internal condensation risk
- Mechanical vibration
- Low antenna height above pavement
- Possible partial obstruction by snow, dirt, or debris

5. LoRaWAN Device Class Analysis

5.1 Class A

Class A is the lowest-power LoRaWAN operating mode and should be considered the default operating mode for the SmartReflect node.

Operation:

Node sleeps

↓

Node wakes up

↓

Node transmits uplink

↓

Node opens RX1 receive window

↓

Node opens RX2 receive window

↓

Node returns to sleep

Advantages

- Lowest energy consumption
- Best fit for solar/battery-powered nodes
- Suitable for event-based reporting
- Supports bidirectional communication
- Gateway can send downlink after node uplink
- Best fit for compact LiFePO₄-powered reflector node

Disadvantages

- Downlink cannot arrive at any arbitrary time
- Cloud command must wait until the node transmits
- Not suitable for immediate real-time actuation
- Requires firmware to stay awake long enough after uplink for RX1/RX2 windows

Assessment for SmartReflect

Class A should be the primary operating mode for the smart road reflector.

Most downlink commands in this project are expected to be configuration commands, not emergency real-time actuation commands. Examples:

Change sampling interval

Change acceleration threshold

Change piezo wake-up threshold

Change reporting schedule

Request diagnostic mode

Change LoRa data rate policy

Request firmware state report

These commands can wait until the node performs its next uplink.

Recommended status:

Primary node mode: LoRaWAN Class A

5.2 Class C

Class C keeps the receiver open most of the time, allowing much lower-latency downlinks.

Operation:

Node transmits uplink

↓

Node keeps receive window open

↓

Cloud can send downlink almost anytime

Advantages

- Low downlink latency
- Cloud can send commands quickly
- Useful for powered devices
- Useful for always-listening infrastructure devices

Disadvantages

- High energy consumption
- Receiver remains active for long periods
- Not suitable for small solar/battery-powered road reflector nodes
- Requires larger energy budget
- May reduce battery life significantly

Assessment for SmartReflect

Class C should not be the normal operating mode for the road reflector node. It may be useful only in special cases:

Bench testing

Gateway/network validation

Temporary diagnostic mode

Externally powered prototypes

Firmware update support

Controlled short-duration field test

Recommended status:

Normal operation: Avoid Class C

Diagnostic/testing mode: Optional

5.3 Recommended Device Class Strategy

The recommended strategy is dual-mode firmware:

Production/default mode:

Class A

Temporary diagnostic mode:

Class C only when explicitly enabled and energy is available

Recommended behavior:

If battery is healthy and debug mode is active:

Allow temporary Class C listening

If battery is low:

Force Class A

If solar input is weak:

Force Class A

If enclosure temperature is too high:

Force Class A or disable radio temporarily

6. Gateway Selection Analysis

6.1 Gateway Requirements

The gateway must support:

- US915 LoRaWAN operation
- 8-channel packet forwarding
- Ethernet backhaul
- Wi-Fi setup or backhaul
- Optional LTE backhaul
- Cloud network server integration
- The Things Stack / TTN compatibility
- ChirpStack compatibility
- Downlink support
- Indoor lab use
- Possible field test use with protected installation
- External antenna connector
- Stable operation for multiple nodes

6.2 Candidate Gateway: RAK Wireless WisGate Edge Lite 2 RAK7268C US915 LTE

The selected gateway candidate is:

RAK Wireless WisGate Edge Lite 2

Model family: RAK7268 / RAK7268C

Region: US915

Optional backhaul: LTE

6.3 Why This Gateway Fits the Project

The RAK7268C is a strong gateway choice for the prototype phase because it provides a balance between cost, capability, and ease of integration.

Main advantages:

- Full 8-channel LoRaWAN gateway
- Supports US915 operation
- Compatible with cloud packet forwarding
- Supports Ethernet connectivity
- Supports Wi-Fi setup or client mode
- Optional LTE backhaul
- Compact indoor form factor
- Web-based configuration
- Good fit for lab testing
- Compatible with common LoRaWAN network servers
- Supports uplink and downlink routing
- Strong ecosystem compatibility with RAK node modules

6.4 Gateway Role in the Architecture

The gateway should not perform heavy application processing during the first prototype phase.

Recommended role:

RF packet reception

LoRaWAN packet forwarding

Cloud backhaul

Downlink packet transmission

Basic gateway diagnostics

Processing should remain in the cloud/backend.

This separation keeps the gateway simple and makes the system scalable.

6.5 Gateway Limitations

The RAK7268C is an indoor gateway. It is appropriate for laboratory development and controlled field tests, but it is not ideal as a permanently exposed outdoor roadside unit unless installed inside a protected enclosure.

Limitations:

- Indoor enclosure rating
- Needs protected mounting location
- Requires power supply
- Gateway antenna placement strongly affects range
- Ground-level nodes require elevated gateway antenna placement
- LTE version increases cost and power requirements
- Not equivalent to a rugged outdoor highway gateway

6.6 Recommended Gateway Usage

For prototype and lab testing:

Use RAK7268C indoors or in a protected location

Connect to TTN or ChirpStack

Use Ethernet when possible

Use LTE only when needed for field tests

Use external antenna connector for range experiments

For later field deployment:

Evaluate outdoor IP-rated gateway

Mount gateway antenna elevated

Use PoE or solar-backed infrastructure power

Use LTE backhaul only where wired internet is unavailable

6.7 Gateway Recommendation

Recommended gateway for current phase:

RAK Wireless WisGate Edge Lite 2 RAK7268C US915 LTE

Reason:

Best balance of cost, LoRaWAN capability, cloud connectivity, bidirectional support, and development convenience.

7. Transceiver / Node Radio Selection Analysis

The node radio decision has two main paths:

1. Use a complete LoRaWAN module with integrated stack.
2. Use a raw transceiver chip and implement the LoRaWAN stack in firmware.

7.1 Option A: RAK3172 LoRaWAN Module

Description

The RAK3172 is a LoRaWAN module based on the STM32WLE5 wireless MCU. It includes the LoRa radio and an MCU capable of running the LoRaWAN stack.

Typical integration method:

ESP32-C3

↓ UART

RAK3172

↓ RF output

Antenna

Advantages

- Strong ecosystem match with RAK gateway
- Supports US915
- Supports LoRaWAN Class A/B/C
- UART AT command interface
- Reduces firmware complexity
- Integrated LoRaWAN stack
- Good for fast prototyping
- Low sleep current
- Reduces risk of RF stack implementation errors
- Good documentation and development ecosystem
- Useful for bidirectional LoRaWAN testing

Disadvantages

- Higher module cost than raw transceiver chip
- Requires communication between ESP32-C3 and module
- May duplicate MCU resources because the module already has an MCU
- Less control than raw SX1262
- Firmware behavior depends on module AT command implementation
- Product cost may be higher than chip-level design

Assessment

The RAK3172 is the best first choice for the prototype because it minimizes software and RF stack risk. It allows the project to focus on sensor behavior, power architecture, housing, antenna placement, and cloud logic.

Recommended status:

Prototype: Strongly recommended

Field prototype: Recommended

Final product: Possible, if cost is acceptable

7.2 Option B: Seeed Wio-E5 Module

Description

The Wio-E5 is another LoRaWAN module based on the STM32WLE5 architecture. It also provides an AT command interface and supports LoRaWAN operation.

Typical integration method:

ESP32-C3

↓ UART

Wio-E5

↓ RF output

Antenna

Advantages

- Compact module
- Low sleep current
- AT command interface
- Good for breadboard and bench testing
- Supports US915
- Useful alternative supplier/module
- Good for fast prototyping
- Based on similar STM32WLE5/SX126x architecture

Disadvantages

- Not the same vendor ecosystem as selected gateway
- Different AT command behavior from RAK modules
- Requires firmware adaptation if switching from RAK3172
- Module variant and certification status must be verified
- May not be preferred if the project standardizes around RAK hardware

Assessment

The Wio-E5 is a good secondary module for comparison or backup. It is valuable as an alternate module, but the RAK3172 is more consistent with the selected RAK gateway ecosystem.

Recommended status:

Prototype backup: Recommended

Second-source evaluation: Recommended

Primary selection: Secondary to RAK3172

7.3 Option C: Semtech SX1262 Raw Transceiver

Description

The SX1262 is a raw LoRa transceiver chip. It provides the RF modem but does not independently provide a complete application-level LoRaWAN device unless the host MCU implements or integrates a LoRaWAN stack.

Typical integration method:

ESP32-C3

↓ SPI

SX1262

↓ RF matching network

Antenna

Advantages

- Excellent RF performance
- High link budget
- High output power capability
- Lower chip-level BOM cost at scale
- Smaller final PCB if designed correctly
- More control over radio firmware
- Better for optimized product design
- Avoids duplicate module MCU
- Can reduce final product cost

Disadvantages

- Higher firmware complexity
- Requires LoRaWAN stack integration
- Requires RF layout expertise
- Requires impedance matching network
- Requires RF validation
- Requires certification effort
- More risk during early prototype
- Longer development time
- SPI integration and radio interrupt handling required

Assessment

The SX1262 is the best long-term custom PCB direction, but it is not the best first prototype path. It should be evaluated after the sensor, housing, battery, antenna placement, and communication architecture are validated with a module.

Recommended status:

First prototype: Not preferred

RF benchmark board: Recommended

Final custom PCB: Strong candidate

8. Transceiver Comparison Matrix

Parameter | RAK3172 | Wio-E5 | SX1262 Raw Chip
Type | LoRaWAN module | LoRaWAN module | Raw transceiver
Host interface | UART AT / RUI API options | UART AT | SPI
LoRaWAN stack | Integrated | Integrated | Host MCU required
Firmware complexity | Low | Low/medium | High
Prototype speed | High | High | Low
Final BOM cost | Medium | Medium | Low at scale
RF layout difficulty | Medium | Medium | High
Sleep power | Very low | Very low | Very low chip-level
Bidirectional support | Good | Good | Depends on stack
Class A support | Yes | Yes | Depends on stack
Class C support | Yes | Yes | Depends on stack
US915 support | Yes | Yes | Yes with correct design
Certification complexity | Lower | Lower | Higher
Best use | Main prototype | Backup module | Final custom PCB

9. Recommended Transceiver Strategy

The recommended development path is staged:

Phase 1:

Use RAK3172 module with the RAK7268C gateway.

Phase 2:

Keep Wio-E5 as an alternate module for comparison.

Phase 3:

Evaluate SX1262 raw transceiver for final custom PCB.

Recommended immediate selection:

Gateway:

RAK7268C US915 LTE

Node module:

RAK3172-T or RAK3172 US915 variant with IPEX/U.FL option if external antenna is needed

Antenna:

Flexible FPC antenna with U.FL connector for first compact housing prototype

For Ohio road conditions, prefer the temperature-rated RAK3172 variant if available and compatible with the required certification and antenna interface.

10. Antenna Selection Analysis

10.1 Antenna Requirements

The antenna is one of the most critical design decisions because the node will be placed close to the ground inside a compact enclosure.

The antenna must:

- Fit inside 125 × 125 × 25 mm housing
- Operate in US915 band
- Be mechanically stable
- Survive vibration and thermal cycling
- Avoid detuning from battery, PCB, metal, and pavement
- Provide acceptable range at pavement level
- Be easy to assemble in prototype units
- Support repeatable RF performance
- Remain inside an RF-transparent housing region

10.2 Main Antenna Options

The viable compact antenna options are:

1. Flexible FPC antenna
2. Ceramic chip antenna
3. Helical spring antenna
4. External gateway antenna upgrade

The gateway antenna is separate from the node antenna but should be evaluated as part of the full link.

11. Option 1: Flexible FPC Antenna

11.1 Description

A flexible FPC antenna is a thin adhesive antenna connected to the PCB through a coaxial cable and U.FL/IPEX connector.

Typical placement:

Inside upper polymer wall

Away from battery

Away from metal

Away from large copper areas

Near RF-transparent housing region

11.2 Advantages

- Best fit for compact reflector housing
- Can be placed away from the main PCB ground plane
- Can be attached to inner plastic wall
- Better RF performance than many chip antennas in constrained layouts
- Low height
- Flexible placement
- Good for prototypes
- Avoids strict chip antenna PCB layout constraints
- Allows antenna position experiments
- Easy to replace during testing

11.3 Disadvantages

- Requires U.FL/IPEX connector
- Requires coax cable routing
- Adds assembly step
- Adhesive bond must survive heat and moisture
- Cable must be strain-relieved
- Antenna performance depends on housing material and placement
- Needs RF validation inside final housing

11.4 Assessment

The FPC antenna is the best first prototype antenna for the SmartReflect node. It provides the best balance of range, compact packaging, and placement flexibility.

Recommended status:

Prototype: Strongly recommended

Field prototype: Recommended

Final product: Strong candidate

12. Option 2: Ceramic Chip Antenna

12.1 Description

A ceramic chip antenna is a small SMD antenna mounted directly on the PCB. It minimizes physical size but requires careful PCB layout.

12.2 Advantages

- Smallest physical antenna option
- Low profile
- No cable
- No manual antenna placement
- Good for automated manufacturing
- Mechanically robust once soldered
- Good for high-volume production if RF layout is validated

12.3 Disadvantages

- Highly sensitive to PCB ground plane design
- Requires strict keep-out area
- Can be detuned by battery and enclosure
- Lower efficiency in constrained housing
- Harder to tune after assembly
- RF range may be reduced near ground level
- Requires VNA tuning and possibly matching network optimization

12.4 Assessment

A ceramic chip antenna is attractive for a future miniaturized production version, but it is not the best first antenna for the prototype because the housing and RF environment are still uncertain.

Recommended status:

Prototype: Not preferred

RF miniaturization study: Recommended

Final compact product: Possible after tuning

13. Option 3: Helical Spring Antenna

13.1 Description

A helical spring antenna is a compact 915 MHz coil antenna soldered directly to the PCB or mounted through a small pad.

13.2 Advantages

- Low cost
- Simple PCB interface
- Better tolerance than some chip antennas
- No coax connector
- Reasonable RF performance
- Easy to test on prototypes
- Can fit if vertical or horizontal clearance is available

13.3 Disadvantages

- Requires physical volume
- May be too tall for a 25 mm housing if vertical
- Can deform under mechanical shock
- Must be protected from compression
- Detunes if bent or near metal
- Less repeatable than FPC in rugged road environment
- May create mechanical reliability concerns

13.4 Assessment

A helical spring antenna is useful for early bench testing and low-cost experiments, but the mechanical risk inside a road reflector is higher than with an FPC antenna.

Recommended status:

Bench testing: Acceptable

Road reflector prototype: Secondary

Final product: Not preferred unless mechanically protected

14. Option 4: Gateway External Antenna Upgrade

14.1 Description

The gateway antenna can be upgraded independently of the node antenna. Raising the gateway antenna and using an appropriate higher-gain external antenna can improve link reliability.

14.2 Advantages

- Improves network coverage without increasing node power
- Does not increase node size
- Does not increase node energy consumption
- Helps compensate for low antenna height of road nodes
- Useful for field testing

14.3 Disadvantages

- Higher-gain antennas must remain compliant with regional EIRP limits
- Outdoor mounting requires lightning and surge protection
- Cable loss can reduce benefit if coax run is long
- Not a substitute for good node antenna design
- Directional or high-gain antenna patterns may create coverage holes

14.4 Assessment

For field tests, the gateway antenna should be elevated and optimized before increasing node transmit power. It is usually better to improve gateway placement and antenna installation than to increase node energy consumption.

Recommended status:

Field test: Recommended

Permanent deployment: Recommended with compliance review

15. Antenna Comparison Matrix

Parameter | FPC Antenna | Ceramic Chip Antenna | Helical Spring Antenna
Space requirement | Low height, medium area | Very small | Medium 3D volume
PCB difficulty | Low/medium | High | Low
Assembly difficulty | Medium | Low after PCB assembly | Low/medium
RF performance in compact housing | Good | Variable | Medium
Sensitivity to ground plane | Medium | High | Medium
Mechanical durability | Good if bonded | Excellent | Medium/low
Prototype flexibility | Excellent | Poor | Medium
Final manufacturability | Medium | Excellent | Medium
Best use | First prototype | Future miniaturized product | Bench/low-cost test

16. Recommended Antenna Strategy

Recommended node antenna for first prototype:

Flexible FPC 902–928 MHz / 915 MHz antenna

Connection: U.FL / IPEX

Placement: inside upper RF-transparent side wall

Recommended alternate antennas to evaluate:

Taoglas FXP290 or similar 915 MHz FPC antenna

Molex 868/915 MHz FPC antenna

Johanson 0915AT43A0026 ceramic chip antenna for miniaturization study

Generic 915 MHz helical spring antenna for bench comparison

Recommended PCB provision:

Add U.FL connector footprint

Add π-matching network footprint

Add optional chip antenna footprint only if PCB space allows

Add RF test point or RF switch footprint if possible

Keep antenna feed short

Maintain 50 Ω controlled impedance trace

Provide antenna keep-out area

17. RF Placement in the Smart Reflector Housing

17.1 Recommended Antenna Location

The antenna should be placed in the RF zone of the housing:

Upper or side internal wall

Behind RF-transparent polymer

Away from LiFePO₄ battery

Away from metal mass

Away from screw bosses if metallic

Away from large PCB copper pours

Away from piezo cantilever mass

Above or laterally offset from main PCB

17.2 Why Not Place the Antenna Near the Battery

The 18650 battery is a large conductive cylindrical object. If the antenna is too close to the cell, it may detune the antenna and reduce radiation efficiency.

Avoid:

Antenna directly beside battery

Antenna under battery

Antenna crossing battery wires

Antenna near steel battery clips

Antenna near large copper planes

17.3 Why the Housing Material Matters

The antenna should radiate through a polymer section of the housing. Avoid metal or carbon-loaded materials near the antenna.

Preferred antenna window materials:

Polycarbonate

PC/ABS

ABS

Other RF-transparent polymer

Avoid near antenna:

Metal inserts

Steel screws

Aluminum shield walls

Carbon-filled plastic

Large copper pours

Battery can

17.4 Recommended RF Zone

The RF zone should be physically defined in CAD and PCB layout.

Recommended RF zone rule:

No battery

No metal mass

No large copper plane

No power inductor

No charger heat source

No piezo tip mass

No structural metal insert

18. Expected Range Analysis

18.1 Theoretical Range

The SX1262-class radio can achieve long range under line-of-sight conditions, especially when paired with a well-placed gateway antenna. However, theoretical range does not represent the smart reflector environment.

18.2 Realistic Road-Level Range

For a node inside a compact road reflector, realistic range is limited by:

- Ground proximity
- Low antenna height
- Pavement absorption
- Vehicle obstruction
- Internal battery shielding
- Enclosure loss
- Small antenna efficiency
- Gateway antenna height
- Urban clutter
- Weather and snow coverage

Expected practical ranges should be validated experimentally.

Preliminary expectation:

Laboratory indoor testing:

Tens to hundreds of meters depending on walls and antenna placement

Outdoor line-of-sight with elevated gateway:

Several kilometers possible

Road-level reflector node with compact internal antenna:

Hundreds of meters is a more realistic initial design target

For the first field test, the project should not assume 10+ km range from a ground-level reflector node. The gateway antenna must be elevated and the node antenna must be carefully placed.

19. Cloud and Network Server Strategy

19.1 Recommended Prototype Network

For early development:

Network server:

The Things Stack / TTN or ChirpStack

Gateway:

RAK7268C as packet forwarder

Application backend:

MQTT, webhook, Node-RED, FastAPI, AWS, or similar

19.2 Why Use Cloud Processing

Cloud processing allows:

- Centralized analytics
- Easier model updates
- Fleet monitoring
- Gateway-independent logic
- Long-term data storage
- Remote configuration
- Scalable dashboards
- Integration with maps or road-condition systems

19.3 Downlink Payload Strategy

Downlinks should be compact byte-level payloads, not JSON strings.

Recommended downlink format:

Byte 0: command ID

Byte 1: parameter ID

Byte 2–N: compact value

Example commands:

0x01: Set reporting interval

0x02: Set accelerometer threshold

0x03: Enable diagnostic mode

0x04: Request battery report

0x05: Change sampling window

0x06: Change LoRa data rate policy

0x07: Enter temporary Class C mode

Payloads should typically remain very short to reduce airtime, energy use, and downlink congestion.

20. Power Management Considerations

20.1 Radio Power Strategy

The radio must be off or asleep most of the time.

Recommended operation:

ESP32-C3 deep sleep

↓

Piezo wake-up event

↓

ESP32 enables accelerometer and radio

↓

Node transmits uplink

↓

Node waits for RX1/RX2 downlink windows

↓

Node processes optional command

↓

Radio returns to sleep

20.2 Avoiding Excessive Downlink Energy

Downlinks require the node to keep the receiver active at scheduled times. Frequent downlinks increase energy consumption and reduce battery life.

Recommended policy:

Use uplink-driven downlinks

Avoid frequent confirmed messages

Avoid Class C except during debug

Batch configuration commands

Use short payloads

Let the node sleep aggressively

20.3 Transmit Power Policy

Do not always transmit at maximum power unless needed.

Recommended policy:

Start with conservative transmit power

Measure RSSI/SNR

Use ADR where appropriate

Increase power only if link margin is poor

Avoid maximum TX power during normal operation unless field data justifies it

For a road-level node, antenna placement and gateway elevation will usually matter more than small changes in transmit power.

21. Regulatory and Certification Considerations

21.1 US915 Operation

The system should use US915 regional settings for operation in the United States.

Required checks:

Correct frequency plan

Correct sub-band configuration

Correct gateway channel plan

Correct node channel mask

FCC-compliant module or certified radio path

Antenna gain compliance

EIRP compliance

Duty cycle / dwell time compliance where applicable

21.2 Module vs. Raw Chip Certification

Using a certified LoRaWAN module can reduce certification risk.

Comparison:

Certified module:

Lower certification burden

Faster prototype-to-product path

Less RF design risk

Raw SX1262:

More design freedom

Lower cost at scale

Higher RF/certification burden

Requires full RF validation

For early prototypes, certified modules are preferable.

22. Supply Chain and Export / Import Cost Risk

The communication subsystem should be evaluated for procurement risk.

Factors to review:

Distributor availability

Lead time

Module lifecycle status

Certification variant availability

US915 variant availability

Antenna connector variant availability

Tariff/import cost

Country of origin

Minimum order quantity

Second-source alternatives

Recommended purchasing strategy:

Prototype:

Buy from authorized distributors or manufacturer store

Field prototype:

Standardize one main module and one backup module

Product:

Request formal production quotes and confirm tariff/import exposure before design freeze

Do not freeze the PCB until the exact radio module part number, antenna connector option, certification variant, and frequency variant are confirmed.

23. Recommended Prototype Architecture

The recommended first prototype configuration is:

Gateway:

RAK WisGate Edge Lite 2 RAK7268C US915 LTE

Network server:

The Things Stack / TTN for lab

ChirpStack or commercial TTI/AWS option for scaling review

Node transceiver:

RAK3172 US915 variant with IPEX/U.FL antenna interface

Node MCU:

ESP32-C3

Antenna:

915 MHz flexible FPC antenna with U.FL/IPEX connector

Operating mode:

LoRaWAN Class A by default

Class C only for temporary diagnostics

RF placement:

Antenna in upper/side RF-transparent housing zone

Battery on opposite side

PCB with 50 Ω RF feed and π-matching footprint

24. Recommended Final Product Direction

The recommended long-term direction is:

Short term:

RAK3172 module for working prototype

Medium term:

Compare RAK3172 against Wio-E5 and SX1262 evaluation board

Long term:

Decide between certified module and raw SX1262 based on volume, cost, certification path, and engineering resources

Decision rule:

If development speed and certification simplicity are more important:

Use RAK3172 module

If unit cost at scale becomes the dominant constraint:

Evaluate raw SX1262 custom design

If RAK supply or pricing becomes problematic:

Evaluate Wio-E5 as alternate module

25. Test Plan

25.1 Gateway Test

Test:

Gateway registration

US915 frequency plan

Ethernet backhaul

Wi-Fi backhaul

LTE backhaul if available

Packet forwarder mode

Cloud uplink reception

Cloud downlink scheduling

Gateway RSSI/SNR reporting

Deliverables:

Gateway configuration report

Network server integration report

Uplink/downlink test log

25.2 Transceiver Test

Test:

RAK3172 Class A uplink

RAK3172 downlink RX1/RX2

Temporary Class C behavior

Sleep current

TX current

RX current

Join time

Rejoin behavior

Payload encoding

Failure recovery

Deliverables:

Radio power profile

LoRaWAN command interface document

Downlink payload format

Firmware state machine

25.3 Antenna Test

Test:

FPC antenna mounted in different housing locations

Antenna near battery versus away from battery

Antenna under polymer wall

Antenna near metal screw bosses

Housing open versus closed

Ground-level performance

Gateway antenna elevation changes

RSSI/SNR at multiple distances

Deliverables:

Antenna placement recommendation

RF layout guideline

Range test report

Housing RF loss estimate

25.4 Field Test

Test:

Outdoor short-range test

Road-level placement test

Elevated gateway test

Battery-powered node test

Solar charging active

Event-driven uplinks

Downlink configuration updates

RSSI/SNR over time

Temperature impact on radio behavior

Deliverables:

Field communication report

Recommended transmit power

Recommended data rate

Recommended antenna placement

Final gateway placement guideline

26. Risk Register

Risk | Severity | Likelihood | Mitigation
Poor range from ground-level node | High | High | Use FPC antenna, elevate gateway antenna, optimize RF zone
Antenna detuning from battery | High | Medium/high | Place antenna away from 18650 and metal
Excessive downlink energy | Medium/high | Medium | Use Class A, short downlinks, avoid frequent Class C
Firmware complexity with raw SX1262 | High | Medium | Use RAK3172 for prototype
Gateway not suitable for outdoor deployment | Medium | Medium | Use protected install or outdoor gateway later
Wrong US915 sub-band configuration | High | Medium | Validate channel plan in gateway and node
RF loss due to housing material | Medium/high | Medium | Use RF-transparent polymer and test closed housing
Certification delay | High | Medium | Use certified module during prototype/product bridge
Import/tariff cost variation | Medium | Medium | Verify final quote and supplier country of origin
U.FL cable/connector failure | Medium | Medium | Strain relief, adhesive retention, vibration testing
Excessive transmit power consumption | Medium | Medium | Use link budget measurements and ADR strategy

27. Final Recommendation

The recommended communication architecture for the current SmartReflect prototype is:

Gateway:

RAK Wireless WisGate Edge Lite 2 RAK7268C US915 LTE

Node radio:

RAK3172 US915 LoRaWAN module

Antenna:

915 MHz flexible FPC antenna with U.FL/IPEX connector

Operating mode:

LoRaWAN Class A by default

Cloud architecture:

Gateway as packet forwarder

Cloud-based processing

Short byte-level downlink commands

The RAK7268C provides the right development gateway capability for bidirectional LoRaWAN testing. The RAK3172 minimizes firmware and LoRaWAN stack complexity, which is valuable during the prototype stage. The flexible FPC antenna is the best first antenna option because it can be placed away from the battery and attached to an RF-transparent area of the housing.

The raw SX1262 should remain the preferred long-term custom PCB direction only after the project validates sensor detection, power budget, antenna placement, housing RF behavior, and cloud downlink control.

The most important RF design rule for the road reflector is:

Use a low-power LoRaWAN module first, place the antenna away from the battery and metal, operate the node in Class A, and validate real range from pavement level before optimizing for final cost.

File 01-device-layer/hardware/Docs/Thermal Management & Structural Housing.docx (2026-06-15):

Technical Analysis: Thermal Management & Structural Housing for Smart Road Infrastructure

Document Reference: TA-2026-003
Project: SmartReflect Platform Integration
Prepared For: Smart Road Reflector Prototype Development

1. Problem Statement

Autonomous, long-term deployment of smart pavement intelligence nodes requires a highly optimized physical housing. The system must operate reliably in harsh outdoor roadway environments while maintaining structural integrity, sensor performance, RF communication reliability, and long-term energy autonomy.

The primary engineering challenge is to identify the best road reflector housing architecture that balances the following competing requirements:

- Cost
- Physical size
- Internal volume
- Mechanical strength
- Material durability
- RF signal transmission
- Solar exposure
- Thermal protection
- Battery safety
- Cold-weather operation
- Summer heat rejection
- Water and salt resistance
- Snowplow compatibility
- Installation complexity
- Manufacturability
- Long-term serviceability

The housing must support a complete embedded system, including:

- LiFePO₄ 18650 battery
- CN3058E LiFePO₄ charger
- Buck-boost regulator
- ESP32-C3 microcontroller
- LoRa radio module
- Piezoelectric wake-up sensor
- Accelerometer
- NTC temperature sensors
- Solar input or external energy input
- Sealed enclosure
- Mechanical coupling to pavement vibration

The problem is not only to fit electronics inside a road reflector. The real problem is to design a road-rated enclosure that can protect the electronics, transfer useful vibration to the sensors, survive Ohio roadway conditions, and remain economically scalable.

2. Key Engineering Problem

The project must find the optimal balance between structural ruggedness, thermal control, sensor performance, RF performance, and cost.

The most important trade-offs are:

Low profile vs. internal volume

Mechanical strength vs. RF transparency

Thermal insulation vs. summer heat rejection

Battery protection vs. solar charging efficiency

Standard road-marker geometry vs. custom smart-node integration

Low cost vs. long-term field reliability

Prototype flexibility vs. production manufacturability

For Ohio road deployment, the design must handle:

- Cold winters
- Snow and ice
- Snowplow interaction
- Road salt
- Freeze-thaw cycles
- Rain and standing water
- Summer pavement heating
- Vehicle impact and tire loading
- Vibration and shock
- UV exposure
- Limited winter solar energy

The housing must be treated as a functional subsystem, not just a plastic shell.

3. Functional Requirements

The reflector housing must provide the following functions:

3.1 Mechanical Protection

The enclosure must protect the internal electronics from:

- Tire loads
- Impact
- Vibration
- Installation stress
- Pavement movement
- Snowplow contact
- Debris impact
- Compression loads
- Repeated thermal expansion and contraction

3.2 Environmental Protection

The enclosure must protect against:

- Water ingress
- Condensation
- Road salt
- Oil and road contaminants
- Dust
- Ice formation
- UV degradation
- Thermal cycling

Target environmental protection should be:

Minimum target: IP67

Preferred target: IP68-like sealed design for final product

3.3 Thermal Management

The enclosure must prevent the battery and electronics from operating outside safe limits.

Main thermal requirements:

Prevent LiFePO₄ charging below 0 °C

Prevent charging above approximately 45 °C

Reduce high-power operation above approximately 60 °C

Protect electronics during internal enclosure temperatures near 70 °C

Avoid trapping excessive heat during summer

Avoid allowing battery temperature to drop too rapidly during winter

3.4 RF Transmission

The enclosure must allow LoRa communication.

This creates material constraints:

Metal enclosure:

Excellent mechanical strength

Poor RF transmission unless antenna is externally exposed or isolated

Plastic/polymer enclosure:

Good RF transmission

Lower structural strength unless reinforced

Hybrid enclosure:

Best balance if metal is used as structural base and polymer window is used for RF path

3.5 Sensor Coupling

The enclosure must transfer useful vibration to the sensors.

The accelerometer should be mounted rigidly to a structural reference point. The piezoelectric sensor may use a cantilever or amplified mechanical structure.

Accelerometer:

Rigid mechanical coupling preferred

Piezoelectric sensor:

Cantilever/mass structure preferred for mechanical amplification

4. System Architecture Assumption

The housing will support the following low-power operating concept:

System in deep sleep

↓

Piezoelectric sensor detects vibration

↓

Wake-up circuit triggers ESP32-C3

↓

ESP32-C3 enables accelerometer power

↓

Accelerometer captures a short vibration window

↓

ESP32-C3 processes the event

↓

LoRa sends a compact message

↓

System returns to deep sleep

This strategy minimizes sensor and radio energy consumption while allowing the system to detect vehicle events.

5. Candidate Reflector Housing Options

Four road-reflector housing concepts are evaluated:

1. Low-profile square/trapezoidal raised pavement marker
2. Round button raised pavement marker
3. Smart/solar raised pavement marker
4. Snowplowable recessed pavement marker

6. Option A: Low-Profile Square / Trapezoidal Raised Marker

6.1 Description

This form factor resembles common non-plowable raised pavement markers. A typical reference size is approximately:

Length: ~100 mm

Width: ~100 mm

Height: ~18–20 mm

This option provides the most compact and standardized geometry.

6.2 Advantages

- Lowest profile
- Lower material usage
- Lower cost potential
- Good aerodynamic/tire interaction
- Easier to visually integrate with existing road markers
- Lower protrusion above pavement
- Less likely to be directly impacted than taller housings
- Simple geometry for early mechanical prototyping

6.3 Disadvantages

- Very limited internal height
- Difficult to fit an 18650 cell, PCB, antenna, insulation, and sensor structure
- Limited room for thermal separation
- Limited room for piezoelectric mechanical amplification
- Limited room for battery retention and shock isolation
- Difficult to include a solar panel with useful surface area
- Poor fit for field-serviceable design
- May be unsuitable for roads with snowplow exposure unless specifically designed as plowable or recessed

6.4 Thermal Assessment

The low internal volume makes thermal control difficult.

Main thermal concerns:

Small air volume heats quickly in summer

Limited insulation volume for winter

Battery is close to outer shell

Electronics may be thermally coupled to pavement temperature

CN3058E heat cannot be controlled effectively

The CN3058E linear charger may generate localized heat during charging, but using charger inefficiency as a deliberate heater is not recommended as the primary thermal strategy. It is unpredictable, depends on solar input, and may create summer overheating risk.

6.5 Integration Assessment

This option is mechanically attractive but electrically restrictive.

Fitting an 18650 cell is possible only with aggressive internal packaging. The 18 mm battery diameter nearly consumes the full internal height of a 20 mm marker, leaving little room for protective wall thickness, adhesive, PCB clearance, and thermal insulation.

6.6 Recommendation

This option is acceptable for:

Non-solar prototype

Small electronics-only version

Short-term bench/field test

External battery test setup

It is not the best first housing for a complete solar-powered smart reflector using a LiFePO₄ 18650 cell.

Recommended status:

Early proof-of-concept: Possible

Full smart node prototype: Not preferred

Final product: Only if electronics are miniaturized significantly

7. Option B: Round Button Raised Marker

7.1 Description

This form factor uses a circular or dome-like housing.

Reference geometry:

Diameter: ~120–130 mm

Height: ~25 mm

The round shape provides more usable horizontal space than the square low-profile marker while maintaining a compact footprint.

7.2 Advantages

- Better internal volume than low-profile square marker
- Circular layout supports centralized PCB design
- More room for battery placement
- More room for antenna separation
- Better opportunity for internal thermal zoning
- Better opportunity for piezoelectric cantilever structure
- Good candidate for prototype iteration
- Can provide more solar panel surface area than a small square marker

7.3 Disadvantages

- Taller than low-profile markers
- More exposed to tire impact
- Higher impact stress at highway speed
- May be more vulnerable to snowplows
- Requires stronger material selection
- Requires careful sloped/domed geometry to reduce impact concentration
- More custom than standard square markers
- Potentially higher tooling cost

7.4 Thermal Assessment

The round button format gives more freedom for thermal design.

Possible thermal zones:

Central warm zone:

Battery + NTC + charger

Outer electronics zone:

MCU + LoRa + sensors

Upper solar zone:

Solar panel + transparent or translucent cover

Lower structural zone:

Rigid base coupled to pavement vibration

The increased volume allows limited use of insulation, air gaps, and internal thermal barriers. However, a sealed round marker may still overheat in summer if it has a dark top surface or poor heat rejection.

7.5 RF Assessment

A polymer round housing is favorable for LoRa transmission. If metal reinforcement is used, the antenna should be located near a polymer window or isolated from the metal structure.

7.6 Integration Assessment

This is a strong prototype option because it provides enough space to test different internal layouts without immediately requiring extreme miniaturization.

7.7 Recommendation

The round button marker is a good intermediate option for early integrated prototypes.

Recommended status:

Early integrated prototype: Recommended

Field prototype: Possible with ruggedization

Final product: Possible if snowplow risk is low or installation location is protected

8. Option C: Smart / Solar Raised Marker

8.1 Description

This form factor is designed natively for electronics and solar charging.

Reference geometry:

Length: ~125 mm

Width: ~125 mm

Height: ~25 mm

This option resembles commercial solar road studs or smart raised pavement markers.

8.2 Advantages

- Designed for embedded electronics
- More internal volume
- Better battery integration
- Better solar panel integration
- Better thermal zoning
- Better room for antenna placement
- Better room for sealing features
- Better room for mechanical sensor amplification
- Best fit for a complete functional prototype
- Easier to integrate CN3058E, battery, buck-boost regulator, LoRa, and sensors

8.3 Disadvantages

- Higher unit cost
- Larger footprint
- More visible as a custom device
- Higher installation adhesive area
- Higher exposure to tire impact
- May not be compatible with snowplow-heavy road sections unless specifically engineered
- Requires more careful material selection
- May require custom tooling for production

8.4 Thermal Assessment

This is the strongest thermal-management option among raised non-recessed housings.

Possible thermal strategy:

Battery located in an insulated cavity

NTC mounted directly to battery

CN3058E placed near but thermally controlled relative to battery

Buck-boost regulator separated from battery

Solar panel thermally decoupled from battery where possible

Internal air gap used as thermal buffer

Light-colored or reflective top surface used where possible

Firmware blocks charging below 0 °C and above high-temperature limit

The design should not rely on charger heat as the primary winter-heating method. Charger heat may be treated as incidental heat, but battery safety must be controlled by temperature-based charge enable/disable logic.

8.5 RF Assessment

A polymer top and side structure allows better RF behavior. The LoRa antenna should be placed away from the battery, copper pours, metal screws, and any metal reinforcement.

Recommended RF strategy:

Keep antenna near polymer wall

Avoid metal directly above or beside antenna

Maintain ground clearance according to antenna datasheet

Avoid fully metallic enclosures

Test RSSI/SNR with final housing material

8.6 Integration Assessment

This is the best option for the first complete field-capable smart-node prototype because it provides enough space for electronics, energy storage, thermal testing, and sensor optimization.

8.7 Recommendation

Recommended status:

Complete prototype: Strongly recommended

Field prototype: Recommended

Final product: Strong candidate if cost is acceptable

9. Option D: Snowplowable Recessed Pavement Marker

9.1 Description

A snowplowable or recessed pavement marker is designed so that snowplows can pass over it with reduced direct impact. Traditional versions may use a cast or reinforced housing, with the reflective or illuminated element protected inside a recessed or ramped structure.

For Ohio roads, this option deserves serious consideration because snowplow interaction is a major deployment risk.

9.2 Advantages

- Best snowplow survivability
- Better protection from direct blade impact
- More suitable for public road deployment in snow regions
- Better long-term mechanical durability
- Can protect optical and electronic elements
- More realistic for Ohio roadway conditions
- Lower risk of catastrophic housing removal

9.3 Disadvantages

- Highest installation complexity
- May require pavement slot cutting or recess preparation
- More expensive installation process
- More difficult to prototype quickly
- Metal housings may block LoRa RF transmission
- Limited internal geometry depending on marker style
- More difficult battery replacement
- More difficult waterproof sealing
- May need external or isolated antenna region
- May require specialized road contractor support

9.4 Thermal Assessment

A recessed design is thermally coupled to the pavement more strongly than raised polymer markers.

This can be beneficial in some cases:

Winter:

Pavement thermal mass may reduce rapid temperature swings

Summer:

Pavement and asphalt may transfer significant heat into the housing

Thermal behavior must be measured, not assumed.

9.5 RF Assessment

If the housing uses metal or cast structure, RF performance can be a major concern. The antenna may need:

- RF-transparent window
- External protected antenna zone
- Polymer insert
- Carefully placed antenna cavity
- Ground plane tuning
- Field RSSI/SNR validation

9.6 Integration Assessment

This option is not the fastest prototype path, but it may be the most realistic final product path for Ohio public roads.

9.7 Recommendation

Recommended status:

Early prototype: Not recommended

Controlled field prototype: Possible

Final Ohio road product: Strong candidate

10. Material Options

10.1 ABS

Advantages

- Low cost
- Easy to mold
- Good impact resistance
- Common in road marker products
- Good for prototypes

Disadvantages

- UV degradation unless stabilized
- Lower high-temperature performance than engineering plastics
- May deform under sustained heat and load
- Requires additives or coatings for outdoor durability

Recommended use:

Early prototype housing

Non-final low-cost enclosure

10.2 Polycarbonate

Advantages

- High impact resistance
- Better toughness than standard ABS
- Good RF transparency
- Good candidate for top cover
- Available in UV-stabilized grades
- Can be transparent or translucent for solar/light functions

Disadvantages

- Higher cost than ABS
- Can scratch
- Chemical resistance must be verified
- Needs UV-stabilized grade for outdoor use

Recommended use:

Top cover

RF-transparent region

Solar window

Impact-resistant shell

10.3 PMMA / Acrylic

Advantages

- Good optical clarity
- Good UV resistance
- Useful for lenses or solar windows
- Good surface hardness

Disadvantages

- More brittle than polycarbonate
- Lower impact resistance
- Not ideal as main structural body

Recommended use:

Lens area

Optical window

Protected solar cover

10.4 Aluminum

Advantages

- Strong
- Good thermal conductivity
- Good heat spreading
- Good mechanical base material
- Corrosion-resistant if treated properly

Disadvantages

- Blocks or detunes RF signals
- Conducts heat into and out of battery region
- Can create galvanic corrosion concerns
- Higher manufacturing cost
- May require polymer RF window

Recommended use:

Structural base

Heat spreader

Reinforcement insert

Not recommended as full RF enclosure

10.5 Stainless Steel

Advantages

- Excellent durability
- Excellent corrosion resistance
- Strong for snowplow and impact protection

Disadvantages

- High cost
- Difficult manufacturing
- Heavy
- Poor RF transparency
- Strong thermal conduction
- May be excessive for early prototype

Recommended use:

Snowplow protection rails

Fasteners

Localized reinforcement

Not recommended as full smart-node enclosure

10.6 Potting Compounds

Advantages

- Waterproofing
- Vibration protection
- Mechanical stabilization
- Tamper resistance

Disadvantages

- Can trap heat
- Makes rework difficult
- Can stress components during thermal cycling
- Can reduce sensor sensitivity if applied incorrectly
- Can make battery replacement impossible

Recommended use:

Selective potting for electronics

Avoid fully potting battery

Avoid potting accelerometer in flexible material if vibration accuracy is needed

11. Thermal Management Strategy

11.1 Key Thermal Risks

The main thermal risks are:

LiFePO₄ charging below 0 °C

Battery overheating during summer

Internal enclosure heating above ambient

CN3058E heat concentration

Buck-boost regulator heat

Solar panel heating

Poor heat dissipation in sealed enclosure

Sensor drift due to temperature

Condensation and freeze-thaw stress

11.2 Required Thermal Sensors

Minimum recommended sensor placement:

NTC 1:

Directly attached to battery cell

NTC 2:

Internal air/enclosure temperature

Optional NTC 3:

Near charger/regulator thermal zone

Optional NTC 4:

Near solar panel or top cover

11.3 Firmware Thermal Control

Minimum LiFePO₄ thermal logic:

If battery temperature < 0 °C:

Disable solar charging

If battery temperature is between 0 °C and 45 °C:

Allow charging

If battery temperature > 45 °C:

Disable or reduce charging

If internal temperature > 60 °C:

Disable high-power functions

If internal temperature > 70 °C:

Enter protective shutdown mode

11.4 CN3058E Heat Consideration

The CN3058E is a linear charger. It dissipates heat based on input voltage, battery voltage, and charge current.

Approximate thermal loss:

Power loss ≈ (VIN - VBAT) × ICHG

Example:

VIN = 5.0 V

VBAT = 3.2 V

ICHG = 0.2 A

Power loss ≈ (5.0 - 3.2) × 0.2

Power loss ≈ 0.36 W

This heat can warm the PCB locally, but it should not be treated as a reliable battery heater.

Risks of using charger heat as a heater:

- Heat only exists when solar input is available
- Heat depends on battery state of charge
- Heat increases summer thermal risk
- Heat may be localized at charger IC, not battery core
- Charge should be disabled below 0 °C for LiFePO₄ anyway
- Using charge current to heat a cold LiFePO₄ cell can be unsafe

Preferred strategy:

Use temperature-based charge blocking

Use insulation to slow battery cooling

Use low-power operation during freezing conditions

Evaluate LTO chemistry if cold charging becomes mandatory

12. Structural Design Strategy

12.1 Internal Zoning

The enclosure should be divided into functional zones:

Zone A: Battery thermal zone

- LiFePO₄ 18650

- NTC attached to battery

- Mechanical retention

- Thermal insulation

Zone B: Power electronics zone

- CN3058E

- Buck-boost regulator

- Protection circuitry

- Solar input protection

Zone C: Sensor zone

- Accelerometer rigidly mounted

- Piezoelectric cantilever or mechanical amplifier

Zone D: RF zone

- LoRa antenna

- RF-transparent housing wall

- Separation from metal and battery

Zone E: Optical/solar zone

- Solar panel

- Transparent or translucent protective cover

12.2 Battery Mounting

The battery must be retained mechanically.

Required features:

- No loose cell movement
- Shock absorption without excessive thermal insulation
- No direct compression on cell casing
- Electrical insulation
- Corrosion-resistant contacts
- Strain relief on wires
- Controlled venting or safe failure path
- NTC bonded to the cell

12.3 PCB Mounting

The PCB should be mounted to a rigid internal frame.

Requirements:

- Mechanical support against vibration
- No PCB flex near accelerometer
- Thermal isolation from high-heat components
- Coating or sealing against moisture
- Test points available in prototype stage
- Connector strategy for debugging

12.4 Sensor Mounting

Recommended approach:

Accelerometer:

Rigid mount to structural base

Piezoelectric sensor:

Cantilever with small mass for wake-up signal amplification

The accelerometer should not be mounted on a flexible cantilever in the first prototype, because it may measure the resonance of the cantilever rather than true pavement vibration.

13. Comparative Housing Matrix

Parameter | Option A: Low-Profile Square | Option B: Round Button | Option C: Smart/Solar Marker | Option D: Snowplowable Recessed
Internal volume | Low | Medium | High | Medium
18650 integration | Difficult | Possible | Good | Depends on structure
Solar integration | Poor/limited | Medium | Good | Difficult
Thermal zoning | Poor | Medium | Good | Medium
Snowplow survivability | Poor unless specially designed | Poor/medium | Poor/medium | High
RF performance | Good if polymer | Good if polymer | Good if polymer | Difficult if metal
Prototype speed | High | High | Medium | Low
Installation complexity | Low | Low/medium | Medium | High
Unit cost | Low | Medium | Medium/high | High
Product realism for Ohio | Low/medium | Medium | Medium | High
Best use | Miniaturized node | Early integrated prototype | Complete smart prototype | Final road-ready direction
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

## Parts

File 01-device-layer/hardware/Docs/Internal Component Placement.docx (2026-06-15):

Technical Analysis: Internal Component Placement for Smart Road Reflector Platform

Document Reference: TA-2026-004
Project: SmartReflect Platform Integration
Subject: Internal Component Placement, Thermal Zoning, Sensor Coupling, and Housing Architecture

1. Problem Statement

The SmartReflect platform requires an optimized internal component layout to support reliable operation inside a compact road-mounted reflector housing. The device must integrate sensing, power management, solar charging, wireless communication, and environmental protection while operating in harsh roadway conditions.

The main engineering challenge is to determine where each internal component should be placed so that the system achieves the best balance between:

- Mechanical durability
- Vibration transfer
- Sensor accuracy
- Thermal protection
- Battery safety
- RF performance
- Solar charging efficiency
- Water and salt resistance
- Manufacturability
- Cost
- Size constraints
- Serviceability
- Long-term reliability

The reflector housing is not only a mechanical enclosure. It functions as a combined structural, thermal, RF, sensing, and environmental protection subsystem.

The internal layout must therefore be designed as a system-level architecture, not as a simple packaging exercise.

2. System Context

The proposed SmartReflect node includes the following major subsystems:

- LiFePO₄ 18650 battery
- CN3058E LiFePO₄ solar charger
- 3.3 V buck-boost regulator
- ESP32-C3 microcontroller
- LoRa communication module
- LoRa antenna
- Piezoelectric wake-up sensor
- Accelerometer, such as BMA400 or equivalent
- Battery NTC thermistor
- Internal enclosure temperature sensor
- Power-stage temperature sensor
- Solar panel
- Protection circuitry
- Sealed road-rated housing
- Mechanical sensor mounting structure

The intended low-power operating sequence is:

System in deep sleep

↓

Piezoelectric element detects vibration

↓

Wake-up circuit triggers ESP32-C3

↓

ESP32-C3 enables accelerometer power

↓

Accelerometer captures short vibration window

↓

ESP32-C3 processes event features

↓

LoRa sends compact message

↓

System returns to deep sleep

This operating strategy allows the accelerometer, LoRa module, and other subsystems to remain off or in low-power states most of the time.

3. Placement Design Objectives

The internal placement must satisfy six major objectives.

3.1 Mechanical Objective

The device must survive tire loading, vibration, installation stress, pavement movement, and impact. Components must be mechanically secured and protected from shock.

3.2 Thermal Objective

The battery, charger, regulator, and electronics must remain within safe operating limits. The layout must prevent unsafe cold charging and summer overheating.

3.3 Sensor Objective

The accelerometer and piezoelectric element must be positioned to capture useful roadway vibration while minimizing false signals caused by loose internal structures.

3.4 RF Objective

The LoRa antenna must be placed where the housing material, battery, copper pours, and metal structures do not excessively attenuate or detune the RF signal.

3.5 Environmental Objective

The layout must reduce water ingress risk, corrosion exposure, condensation problems, and salt-related damage.

3.6 Manufacturing Objective

The design should be easy to assemble, test, seal, and eventually produce at scale.

4. Recommended Internal Zoning

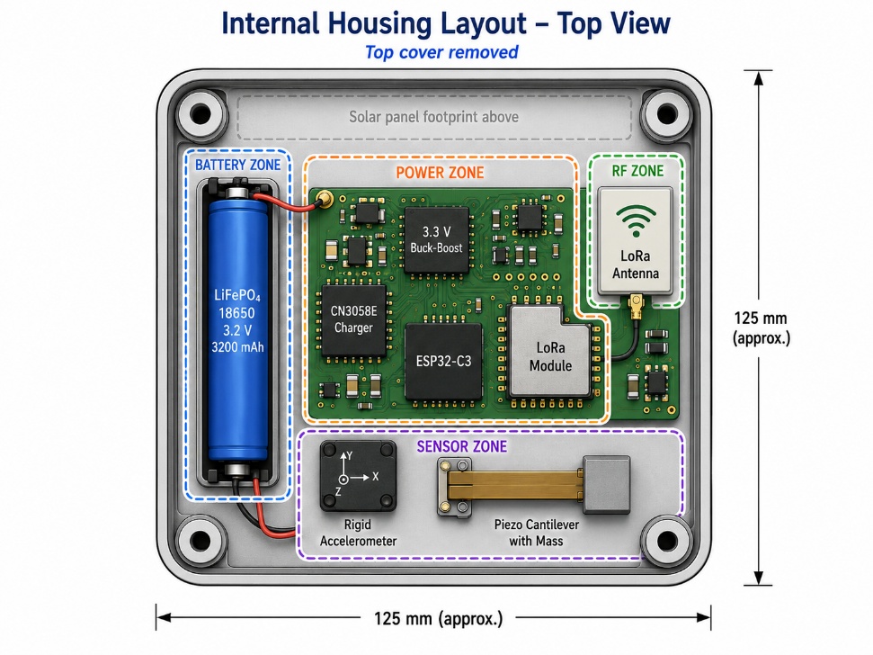
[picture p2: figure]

The reflector should be divided into functional internal zones.

Top Layer:

Solar panel / optical cover / environmental cover

Upper Internal Layer:

Antenna zone

Internal temperature sensing

Solar input routing

Middle Internal Layer:

Battery zone

Power electronics zone

Main PCB

Lower Internal Layer:

Accelerometer rigid mount

Piezoelectric mechanical amplifier

Structural base coupled to pavement

Bottom Layer:

Adhesive / mechanical interface to pavement

Recommended zone layout:

Top View - Conceptual Layout

┌─────────────────────────────────────────────┐

│ Solar Panel Area │

│ │

│ Battery Zone RF Zone │

│ LiFePO₄ 18650 LoRa Antenna │

│ Battery NTC Polymer Wall │

│ │

│ Power Zone MCU Zone │

│ CN3058E ESP32-C3 │

│ Buck-Boost LoRa Module │

│ Protection Debug Pads │

│ │

│ Sensor Zone │

│ Rigid Accelerometer + Piezo Cantilever │

└─────────────────────────────────────────────┘

Side view:

Side Section - Conceptual Layout

Solar panel / top protective window

┌─────────────────────────────────────┐

│ Upper cavity / RF-transparent area │

│ Internal temperature sensor │

│ │

│ LiFePO₄ 18650 + battery NTC │

│ │

│ Main PCB: charger, regulator, MCU │

│ │

│ Accelerometer rigidly mounted │

│ Piezo cantilever + small mass │

└─────────────────────────────────────┘

Structural base bonded to pavement

5. Battery Placement

5.1 Recommended Location

The LiFePO₄ 18650 battery should be placed in a dedicated battery zone, preferably along one side of the housing or in a central protected cavity depending on the available geometry.

Recommended placement:

Middle layer

Mechanically protected cavity

Away from direct solar panel heat

Away from antenna keep-out area

Close enough to charger to reduce wiring loss

Thermally monitored with direct NTC contact

5.2 Why the Battery Should Not Be Near the Top Surface

The top surface of the reflector may become hot under direct sun exposure. Placing the battery directly under the solar panel or top cover increases the risk of summer overheating.

Main risks:

- Higher battery temperature during summer
- Reduced battery lifetime
- Higher risk of charging cutoff due to high temperature
- Higher thermal stress
- Larger temperature swings

5.3 Why the Battery Should Not Be at the Extreme Bottom Without Isolation

The bottom of the housing is mechanically and thermally coupled to the pavement. In winter, this can expose the battery to cold pavement temperature. In summer, it can expose the battery to hot asphalt temperature.

A direct bottom placement can cause:

- Faster cooling during winter
- Higher heat transfer from pavement during summer
- Larger thermal cycling
- Mechanical shock transfer into the cell

5.4 Recommended Battery Mounting Strategy

The battery should be retained using a mechanically secure but electrically insulated holder.

Recommended features:

Rigid support structure

No loose movement

No direct compression on cell casing

Electrical insulation

Shock-tolerant retention

NTC attached directly to cell wall

Clearance from sharp edges

Protection from condensation paths

The battery should not be fully potted. Full potting may trap heat, make rework impossible, and place mechanical stress on the cell during thermal expansion.

5.5 Battery Thermal Sensor

A thermistor should be physically attached to the battery body.

Recommended location:

Midpoint on the side wall of the 18650 cell

Direct contact with the metal can

Secured with thermal adhesive or thermal tape

Electrically insulated from the cell body if required

Purpose:

- Prevent charging below 0 °C
- Prevent charging above high-temperature limit
- Detect dangerous internal temperature trends
- Log real battery thermal behavior during field tests

6. CN3058E Charger Placement

6.1 Recommended Location

The CN3058E charger should be placed on the main PCB near the battery zone but not directly underneath or directly touching the battery.

Recommended placement:

Power electronics zone

Near solar input path

Near battery connection

On PCB area with thermal copper

Thermally monitored if possible

Separated from accelerometer and RF antenna

6.2 Reasoning

The CN3058E is a linear charger. It dissipates heat according to input voltage, battery voltage, and charge current.

Approximate heat loss:

Power loss ≈ (VIN - VBAT) × ICHG

This heat can become significant in a sealed enclosure. The charger therefore needs:

- Copper area for heat spreading
- Thermal distance from the battery
- Temperature monitoring
- Firmware or hardware charge disable control
- Protection from summer overheating

6.3 Why It Should Not Be Used as the Primary Battery Heater

Although the charger produces heat, it should not be treated as a reliable heater for cold-weather operation.

Reasons:

- Charger heat only exists when solar energy is available
- Heat depends on charge current
- Charge must be disabled when the LiFePO₄ battery is below 0 °C
- Heat may remain localized at the PCB rather than warming the battery core
- Summer conditions can convert the same heat source into a thermal risk

The charger should be thermally managed, not intentionally relied upon for heating.

7. Buck-Boost Regulator Placement

7.1 Recommended Location

The 3.3 V buck-boost regulator should be placed close to the main load distribution point, near the ESP32-C3 and LoRa module, but thermally separated from the accelerometer and battery.

Recommended placement:

Main PCB power zone

Close to ESP32-C3 and LoRa supply path

Short high-current traces

Good local input/output capacitors

Separated from accelerometer

Separated from RF antenna

Thermal copper area available

7.2 Reasoning

The buck-boost regulator supplies the system from a LiFePO₄ cell whose voltage may be above or below 3.3 V during operation.

The regulator handles:

- ESP32-C3 current peaks
- LoRa transmit current peaks
- Sensor supply current
- Wake-up and active-mode transitions

Poor placement can cause:

- Voltage droop during LoRa transmission
- EMI coupling into the accelerometer
- RF interference
- Excessive thermal concentration
- Reduced regulator efficiency

7.3 Decoupling Requirements

The regulator should have:

Input capacitor close to regulator

Output capacitor close to regulator

Bulk capacitor near LoRa module

Local decoupling near ESP32-C3

Short ground return paths

Wide power traces

The LoRa module should also have a local energy reservoir, typically a larger bulk capacitor, to support transmission peaks.

8. ESP32-C3 Placement

8.1 Recommended Location

The ESP32-C3 should be located on the main PCB in the electronics zone, between the power system and the sensor/RF interfaces.

Recommended placement:

Main PCB central electronics zone

Close to accelerometer interface traces

Close to load-switch control

Close to LoRa UART/SPI interface

Not directly under solar panel hot spot

Not next to high-current charger trace

Accessible to debug/programming pads

8.2 Reasoning

The ESP32-C3 controls:

- System sleep/wake behavior
- Piezo wake event interpretation
- Accelerometer power enable
- Sensor sampling
- LoRa communication
- Battery voltage measurement
- Thermal protection logic
- Charge enable/disable behavior

The MCU should be close enough to all controlled subsystems to reduce trace length and noise, but not placed directly next to high-heat or high-current components.

8.3 Debug Access

For prototype units, the layout should include accessible:

UART programming pads

Boot/reset access

Ground test points

3.3 V test point

Battery voltage test point

Solar input test point

I²C/SPI test points

Wake signal test point

These can be removed or reduced in final product versions.

9. LoRa Module and Antenna Placement

9.1 Recommended Location

The LoRa module may be placed on the main PCB, but the antenna must be located near an RF-transparent region of the housing.

Recommended antenna placement:

Near side wall or upper corner

Behind polymer material

Away from battery

Away from metal screws

Away from large copper planes

Away from piezo mass

Away from structural metal inserts

9.2 Why the Antenna Should Be Away From the Battery

The 18650 cell is a large conductive cylindrical object. It can detune or shield the antenna, reducing LoRa range and reliability.

Avoid:

Antenna directly beside battery

Antenna under battery

Antenna surrounded by copper

Antenna behind metal frame

Antenna near steel fasteners

9.3 RF Keep-Out Zone

The antenna should have a defined keep-out area.

Recommended approach:

Use polymer wall or cover near antenna

Keep metal and battery away from antenna field

Avoid ground pour under chip antenna unless required by antenna datasheet

Maintain antenna orientation consistently between prototypes

Validate RSSI/SNR in final housing

9.4 RF vs. Mechanical Trade-Off

A metal-reinforced housing improves structural strength but can degrade RF performance. A polymer housing improves RF but may need reinforcement for road loads.

Recommended compromise:

Hybrid structure:

Metal or reinforced base for strength

Polymer upper or side RF window for LoRa antenna

Antenna located behind RF-transparent wall

10. Accelerometer Placement

10.1 Recommended Location

The accelerometer should be mounted rigidly near the lower structural base of the reflector.

Recommended placement:

Lower PCB or small sensor PCB

Rigidly connected to housing base

Near central structural region

Away from loose covers or flexible panels

Away from power regulator heat

Away from piezo cantilever resonance path

10.2 Why the Accelerometer Should Be Rigidly Mounted

The accelerometer should measure actual reflector or pavement-coupled vibration. If it is mounted on a flexible support, foam, or loose PCB, it may measure the internal resonance of the structure rather than the roadway vibration.

Correct structure:

Pavement

↓

Adhesive layer

↓

Rigid reflector base

↓

Rigid internal mount

↓

Accelerometer PCB

Avoid:

Accelerometer floating on wires

Accelerometer mounted with soft silicone

Accelerometer attached to flexible top cover

Accelerometer placed on same cantilever as piezo

Accelerometer near moving battery holder

10.3 Recommended Mounting Method

For the first prototype:

Mount accelerometer on main PCB if the PCB is rigidly attached to the base

or

Use a small dedicated sensor PCB bolted or bonded to the structural base

For better repeatability, the dedicated sensor PCB is preferred.

10.4 Placement Relative to Center of Housing

The accelerometer should initially be placed near the central lower region of the reflector. This provides a more balanced measurement and reduces sensitivity to local housing flex.

Recommended first placement:

Center-bottom of housing

Rigid base mount

Known X/Y/Z orientation

Orientation should be marked in CAD and firmware documentation.

10.5 Why It Should Be Separated From the Piezo Cantilever

The piezo cantilever is intentionally designed to amplify vibration. The accelerometer should not be placed on that same structure because it may capture exaggerated resonance rather than true road vibration.

Recommended separation:

Piezo:

Flexible amplified structure

Accelerometer:

Rigid reference structure

11. Piezoelectric Sensor Placement

11.1 Recommended Location

The piezoelectric sensor should be mounted inside the reflector as a mechanically amplified wake-up element.

Recommended placement:

Lower internal zone

Anchored to rigid base

Mounted as cantilever or flexing element

Separated from battery and antenna

Protected from direct impact

Not fully potted in rigid resin

11.2 Purpose

The piezoelectric element is not the primary precision measurement sensor. Its main function is to detect mechanical activity and wake the ESP32-C3.

Function:

Road vibration or impact

↓

Piezo mechanical deformation

↓

Electrical pulse

↓

Wake-up circuit

↓

ESP32-C3 deep sleep wake

11.3 Recommended Cantilever Structure

A cantilever structure is recommended for mechanical amplification.

Rigid anchor point

│

├──── flexible beam ─────● small mass

↑

piezo bonded near high-strain region

Recommended initial values for prototype testing:

Beam length: 30 mm to 60 mm

Beam width: 8 mm to 15 mm

Beam thickness: 0.3 mm to 1.0 mm

Tip mass: 1 g to 10 g

Initial mass target: 3 g to 5 g

The piezo should be bonded near the fixed end, where strain is higher.

11.4 Why the Piezo Should Not Be Fully Rigidly Mounted

If the piezo is rigidly clamped across its entire surface, it may not flex enough to generate a useful signal.

Good mounting:

One controlled fixed region

Flexible region allowed to bend

Tip mass for amplification

Mechanical stop to prevent over-flexing

Poor mounting:

Fully embedded in hard potting

Loose inside housing

Pressed directly by battery

Exposed to tire impact

Placed near antenna with metal mass

11.5 Overload Protection

The cantilever should include a mechanical stop to prevent the beam from bending too far during shock events.

Recommended feature:

Small internal stop above/below cantilever

Gap sized to allow normal vibration

Stop prevents destructive deflection

12. Temperature Sensor Placement

12.1 Battery NTC

The most important temperature sensor is the battery NTC.

Location:

Directly attached to LiFePO₄ 18650 cell body

Mid-cell side wall

Thermally coupled

Electrically insulated if needed

Purpose:

Disable charging below 0 °C

Disable charging above high limit

Log battery temperature

Protect battery lifetime

12.2 Internal Air Temperature Sensor

A second temperature sensor should measure internal enclosure temperature.

Location:

Upper-middle internal cavity

Away from direct contact with charger

Away from direct contact with battery

Away from direct solar panel conduction path

Purpose:

Estimate enclosure thermal environment

Detect solar heating

Support thermal model

Trigger reduced operation if enclosure overheats

12.3 Power Stage Temperature Sensor

A third temperature sensor is recommended near the charger and regulator.

Location:

Near CN3058E and buck-boost regulator

On PCB close to thermal copper

Not directly on the IC package

Purpose:

Detect charger overheating

Detect regulator overheating

Validate thermal design

Protect system during high solar input

12.4 Optional Solar Panel Temperature Sensor

For early prototypes, an optional sensor near the solar panel/top cover is useful.

Purpose:

Measure top surface heating

Correlate solar exposure with internal temperature

Improve enclosure thermal model

This sensor may be removed in final production if the data shows it is not needed.

13. Solar Panel Placement

13.1 Recommended Location

The solar panel should be placed on the upper surface of the reflector, protected by a transparent or translucent impact-resistant cover.

Recommended placement:

Top surface

Slightly recessed or flush protected

Mechanically isolated from direct tire shear when possible

Sealed around perimeter

Wired directly to power input protection

13.2 Design Considerations

The solar panel must balance energy harvesting with mechanical survival.

Risks:

- Tire abrasion
- Debris impact
- Snow and dirt coverage
- UV degradation
- Water ingress around edges
- Heat transfer into battery zone
- Reduced efficiency from road grime

Recommended protections:

Recessed panel pocket

UV-stabilized transparent cover

Sealed perimeter

Drainage consideration if applicable

Impact-resistant material above panel

Replaceable panel in prototype stage

13.3 Thermal Consideration

The solar panel can become a heat source under direct sun. The battery should not be directly attached to the solar panel back side.

Recommended separation:

Solar panel

↓

Air gap or thermal barrier

↓

Battery zone offset laterally or lower in structure

14. Protection Circuit Placement

14.1 Battery Protection

Protection circuitry should be close to the battery connection.

Required functions:

Overcharge protection

Overdischarge protection

Short-circuit protection

Reverse polarity protection

Current limiting

Fuse or PTC protection

Recommended location:

Near battery terminal path

Before system power distribution

Accessible to test points in prototype

Separated from antenna area

14.2 Solar Input Protection

Solar input protection should be placed close to the solar panel entry point.

Recommended components/functions:

Reverse current blocking

TVS or transient protection

Input capacitor

Current limiting if required

Connector protection

Purpose:

- Protect charger from transients
- Prevent reverse leakage into panel
- Reduce EMI
- Improve charging reliability

15. Load Switch for Accelerometer

15.1 Recommended Placement

The accelerometer load switch should be placed near the accelerometer power input.

Recommended connection:

3.3 V rail

↓

Load switch controlled by ESP32-C3

↓

VDD_ACCEL

↓

Accelerometer

15.2 Reasoning

The load switch allows the accelerometer to consume approximately zero current when the system is asleep.

This supports the ultra-low-power architecture:

Piezo stays active as wake-up source

Accelerometer remains fully unpowered

ESP32 wakes

ESP32 enables accelerometer

Accelerometer captures data

ESP32 disables accelerometer

15.3 Back-Powering Prevention

If the accelerometer is unpowered, communication lines must not accidentally power it through I²C or SPI pins.

Recommended precautions:

Place I²C pull-ups on switched VDD_ACCEL

Set ESP32 pins to high impedance before powering off sensor

Use series resistors if needed

Avoid always-on pull-ups to 3.3 V on sensor lines

Validate leakage current in deep sleep

16. PCB Placement Strategy

16.1 Main PCB

The main PCB should contain:

- ESP32-C3
- LoRa module interface
- CN3058E charger
- Buck-boost regulator
- Protection circuitry
- Battery voltage measurement
- Temperature sensing inputs
- Accelerometer interface
- Load switch control
- Debug/test points

Recommended PCB placement:

Middle-to-lower internal layer

Mechanically attached to internal frame

Thermally separated from top solar panel

Rigidly connected near accelerometer zone

With antenna keep-out region respected

16.2 Separate Sensor PCB Option

A separate accelerometer PCB may improve measurement repeatability.

Advantages:

- Better mechanical coupling
- Easier orientation control
- Less noise from power circuits
- Easier comparison of different accelerometers
- Better modularity during testing

Disadvantages:

- More connectors or solder points
- More assembly complexity
- Higher prototype cost

Recommended prototype approach:

Use separate accelerometer PCB for testing

Integrate onto main PCB only after mechanical behavior is validated

17. Sealing and Environmental Protection

17.1 Seal Location

The main seal should be located away from high-impact contact areas when possible.

Recommended sealing strategy:

Perimeter gasket or adhesive seal

Conformal coating on PCB

Selective potting for high-risk areas

No full potting of battery

No flexible potting directly around accelerometer

Controlled cable/solar feedthrough sealing

17.2 Condensation Risk

A sealed housing can trap moisture during assembly or field operation.

Mitigation options:

Dry assembly process

Desiccant in prototype units

Conformal coating

Hydrophobic vent for pressure equalization if suitable

Corrosion-resistant contacts

Avoid exposed copper

17.3 Road Salt Protection

Road salt creates corrosion risk.

Recommended protections:

Conformal coating

Sealed battery terminals

Gold-plated or protected contacts where needed

No exposed steel near electronics

Stainless or coated fasteners

Avoid galvanic metal pairs

18. Recommended Final Internal Layout

The recommended first complete prototype layout is:

Top:

Solar panel with protected cover

Upper side/corner:

LoRa antenna behind polymer wall

Middle protected zone:

LiFePO₄ 18650 battery with direct NTC

Main PCB:

CN3058E charger near solar/battery path

Buck-boost regulator near load distribution

ESP32-C3 near control and communication interfaces

LoRa module near antenna feed

Protection circuitry near power entry and battery

Lower rigid zone:

Accelerometer mounted to structural base

Piezoelectric cantilever mounted to rigid base

Thermal sensors:

NTC 1 on battery

NTC 2 internal enclosure air

NTC 3 near power electronics

Optional NTC 4 near solar panel/top cover

Simplified layout:

┌─────────────────────────────────────────────┐

│ Solar panel / protected top cover │

├─────────────────────────────────────────────┤

│ RF Zone: antenna near polymer side wall │

│ Internal temp sensor │

├─────────────────────────────────────────────┤

│ Battery Zone: LiFePO₄ 18650 + battery NTC │

├─────────────────────────────────────────────┤

│ Main PCB: CN3058E / buck-boost / ESP32 / LoRa│

│ Power-stage temp sensor │

├─────────────────────────────────────────────┤

│ Sensor Zone: rigid accelerometer mount │

│ Piezo cantilever + tip mass │

└─────────────────────────────────────────────┘

Pavement bonding surface

19. Component Placement Matrix

Component | Recommended Location | Reason
LiFePO₄ 18650 | Middle protected battery zone | Reduces direct solar and pavement thermal exposure
Battery NTC | Directly attached to battery cell | Required for safe charge inhibition
CN3058E | Power zone near battery and solar input | Minimizes power path length and manages charger heat
Buck-boost regulator | Main PCB near load distribution | Supports stable 3.3 V rail and current peaks
ESP32-C3 | Central electronics zone | Controls wake, sensing, power, and communication
LoRa module | Near antenna feed | Reduces RF feed losses
LoRa antenna | Side/upper RF-transparent region | Minimizes shielding by battery/metal
Accelerometer | Lower rigid structural base | Captures true reflector/pavement vibration
Piezoelectric sensor | Lower cantilever structure | Amplifies vibration for wake-up
Internal temp sensor | Upper-middle internal cavity | Measures enclosure thermal environment
Power temp sensor | Near charger/regulator | Detects local heat generation
Solar panel | Top protected surface | Maximizes energy harvesting
Solar protection | Near solar panel entry | Protects charger from transients
Battery protection | Near battery terminals | Protects against electrical faults
Debug pads | Accessible edge or bottom service area | Supports prototype testing

20. Prototype Validation Plan

20.1 Mechanical Layout Validation

Tasks:

Create CAD model

Place real 18650 model

Place PCB outline

Place solar panel

Place antenna keep-out zone

Place piezo cantilever

Place accelerometer mount

Check assembly clearances

Check seal path

Check screw/fastener locations

Deliverables:

- Internal layout drawing
- Exploded view
- Clearance analysis
- Assembly sequence

20.2 Thermal Validation

Tasks:

Measure battery temperature

Measure enclosure air temperature

Measure charger/regulator temperature

Measure solar panel temperature

Test cold environment

Test hot enclosure condition

Validate charge disable below 0 °C

Validate high-temperature cutoff

Deliverables:

- Thermal map
- Charge inhibit validation
- Summer overheating risk report
- Battery safety recommendation

20.3 Sensor Validation

Tasks:

Compare accelerometer placement options

Validate rigid mounting

Test piezo cantilever response

Measure wake-up success rate

Measure false positives

Capture vehicle vibration events

Compare walking, tapping, and vehicle events

Deliverables:

- Sensor placement recommendation
- Piezo beam/mass recommendation
- Accelerometer threshold settings
- Event feature dataset

20.4 RF Validation

Tasks:

Measure LoRa RSSI/SNR with housing open

Measure LoRa RSSI/SNR with housing closed

Test antenna near different walls

Test antenna near battery vs. away from battery

Test orientation sensitivity

Test ground-level range

Deliverables:

- Antenna location recommendation
- Housing material RF assessment
- LoRa range report

20.5 Environmental Validation

Tasks:

Water ingress screening

Condensation screening

Salt exposure screening

Freeze-thaw cycling

Vibration exposure

Drop/impact testing

Adhesive bond testing

Deliverables:

- Environmental risk report
- Seal design recommendation
- Material recommendation

21. Project-Level Next Steps

21.1 Immediate Prototype Actions

The next prototype should include:

Smart/solar raised marker housing

LiFePO₄ 18650

CN3058E charger

3.3 V buck-boost regulator

ESP32-C3

LoRa module

BMA400 accelerometer or equivalent

Piezoelectric wake-up circuit

Three NTC sensors

Protected solar panel

Accessible debug/test points

21.2 Build Two Internal Layout Variants

Recommended variants:

Variant A:

Battery centered, antenna on side wall, accelerometer on lower center base

Variant B:

Battery offset to one side, antenna opposite side, accelerometer on separate lower sensor PCB

Purpose:

- Compare RF performance
- Compare thermal behavior
- Compare vibration signal quality
- Compare assembly practicality

21.3 Data Collection Priorities

The prototype must log:

Battery voltage

Battery temperature

Internal enclosure temperature

Power-stage temperature

Solar input state

Charge enable/disable state

Wake-up source

Piezo event amplitude

Accelerometer event features

LoRa RSSI/SNR

System current profile

21.4 Design Freeze Criteria

The internal placement should not be frozen until the following are validated:

Battery remains within safe temperature limits

Charging is blocked below 0 °C

Antenna performs acceptably inside housing

Accelerometer detects vehicle-induced vibration

Piezo reliably wakes system

False wake-ups are manageable

Solar charging works in sealed housing

No water ingress path compromises electronics

Assembly process is realistic

Cost is compatible with project targets
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

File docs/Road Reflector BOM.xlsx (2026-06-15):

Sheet: Sheet1
 |  | Tentative Products | Link | Cost | Energy cost (Wh/day) |  |  | ctrl pins
Accelerometer | ADXL362 | ADXL362 High Performances Sensors Module 3 Shaft Accelerometer Motion Sensors Module with SPI Interfaces for 1.6V-3.5V | https://www.amazon.com/QIEIEI-Performances-Accelerometer-Interfaces-1-6V-3-5V/dp/B0FD41Z5D8 | 6.68 | 0.000086000 |  |  | 2
Temperature | NTC encapsulado | 10Pcs 10K NTC Thermistor, 10K 3590B 1% NTC Thermistors Resistors Temperature Sensor, 10K Ohm Thermistor MF52B 3950 1% Wire Length 100mm(3.93in), | https://www.amazon.com/Thermistor-Thermistors-Resistors-Temperature-Sensor/dp/B0F3X2G4D2?language=en_US | 7.99 | 5e-09 |  |  | 1
Water | capacitive Soil Moisture Sensor Module | songhe capacitive Soil Moisture Sensor Module - Corrosion Resistant, 3.3~5.5v for arduino DIY, Compatible with ecowitt & rainpoint (5pcs) | https://www.amazon.com/hiBCTR-songhe-capacitive-Moisture-Sensor/dp/B0FKN2W3NK?sp_csd=d2lkZ2V0TmFtZT1zcF9hdGY | 9.98 | 0.000066000 |  |  | 1
Energy | 2 Watt 6 Volt Small Solar Panel - ETFE | 2 Watt 6 Volt Small Solar Panel - ETFE | https://voltaicsystems.com/P126/?srsltid=AfmBOorQn7Vz1T6sszcZY8jB9jYP3q43JDeSq_EQ0ZxAGKzd1ETK9bIr | 25.99 |  | 0.5W
Energy | LiFePO₄ 18650 | Panasonic NCR18650GA 3450mAh 10A Battery | https://www.18650batterystore.com/products/panasonic-ncr18650ga-ga6?adgroupid=43081474946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 | 6.99
Regulador | Ultra low power step down regulator | TPS62740 - Ultra low power step down regulator | https://www.tindie.com/products/ambergarage/tps62740-ultra-low-power-step-down-regulator/ | 13.95
MCU | esp32 c3 | esp32 c3
Radio | LoRa externo | RYLR998 UART Interface 868/915 MHz Lora Module with Antenna FCC CE NCC IC Certification | https://www.amazon.com/REYAX-RYLR998-Interface-Antenna-Transceiver/dp/B099RM1XMG | 12.6 | 0.000120000 |  | 15km (9 M) | 2
Charger | CN3058E Charger | 5Pcs 15Pcs New Cn3058 Cn3058E New 2026 High for Reliable Electronic Component, Precision, Stable Performance | https://www.amazon.com/Reliable-Electronic-Component-Precision-Performance/dp/B0FS5LZM7B | 19.99
Radio larga distancia | Semtech SX1262 / RAK3172 / Wio-E5
Led | Ambar High-Efficiency
Sellado | Potting parcial + gasket
Antenna | PCB/FPC protegida o externa en cluster leader
Carcasa | Policarbonato + aluminio + encapsulado
 |  |  | total | 104.17 | 0.000272005
Battery | SLB12400L1511CV
 | LiFePO₄ 32700
 | LiFePO₄ 18650

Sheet: Sheet2
 | link | units | unit cost
Battery | https://www.digikey.com/en/products/detail/phd-energy/PHD-18650-LFP-1800/24979267 | 2 | 5
Acelerometer | https://www.amazon.com/gp/product/B0FD41Z5D8/ref=ewc_pr_img_2?smid=A179AK2929BV6U&psc=1 | 2 | 9
 | https://www.amazon.com/JESSINIE-Accelerometer-Acceleration-1-2V-3-6V-Intelligent/dp/B0BBLRTQTX | 2 | 14
LoRa Tranceiver 1st | amazon.com/gp/product/B09LV2W64R/ref=ewc_pr_img_2?smid=A50C560NZEBBE&psc=1 | 2 | 16
Lora Antenna | https://www.digikey.com/en/products/detail/johanson-technology-inc/0915AT43A0026001E/2137136?gclsrc=aw.ds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 | 2 | 2.5
Lora Gateway | https://www.digikey.com/en/products/detail/rakwireless-technology-limited/RAK7268CV2-EG95NA-US915-W/29287290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 | 1 | 298.5
Cantilever Piezo Film | https://www.digikey.com/en/products/detail/te-connectivity-measurement-specialties/1006015-1/5277266 | 2 | 6.5
Thermistor 100k Ohn | https://www.digikey.com/en/products/detail/littelfuse-ibu/PS104J2/1014534 | 4 | 2.5
Resistor 100K Ohm |  | 10
LoRa Tranceiver 2nd | https://store.rakwireless.com/products/wisduo-lpwan-module-rak3172?variant=44068554506438
Lora Antenna | https://store.rakwireless.com/products/pcb-antenna-for-lora-mhf-1

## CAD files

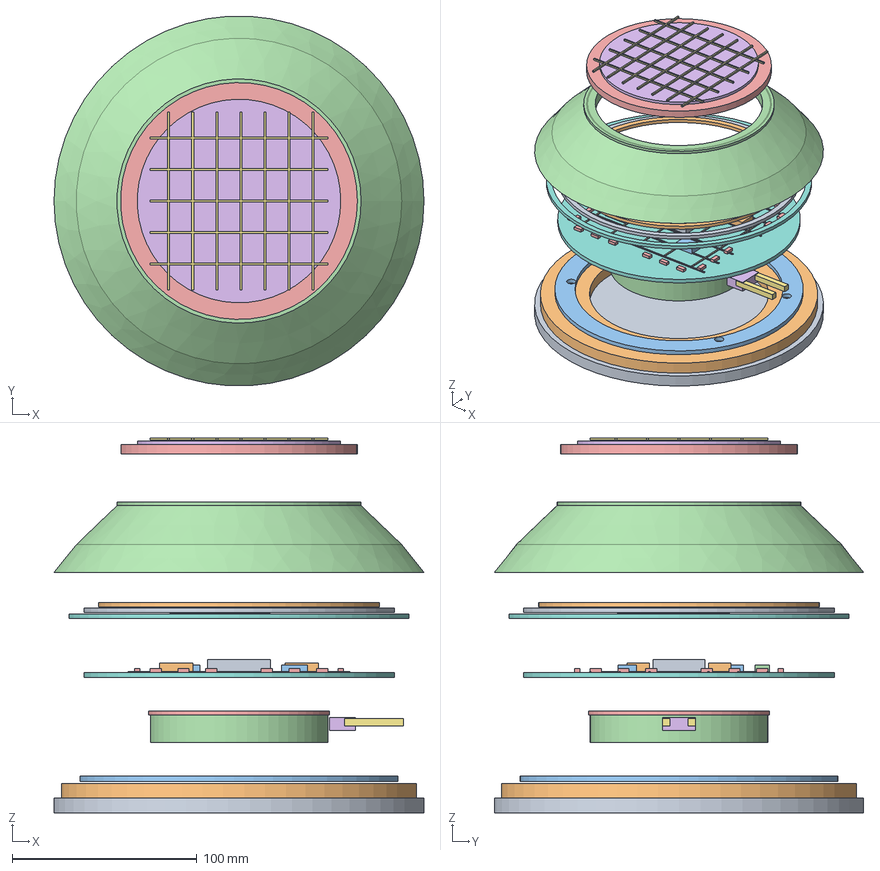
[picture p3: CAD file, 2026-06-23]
SmartRoadReflector_6a.step
200.0 x 199.7 x 202.6 mm
_01_Sealed_Base_Print_Object
_02_Battery_Unit_Print_Object
_03_Populated_PCB_Print_Object
_04_THICK_Antenna_Coil_Print_Object
_05_HOLLOW_Smooth_Top_Housing_NO_Indents_Print_Object
_06_Solar_Panel_Print_Object

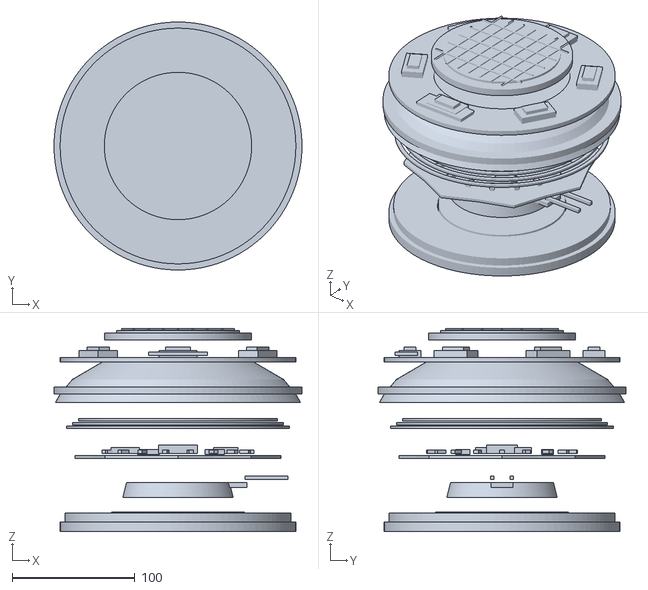
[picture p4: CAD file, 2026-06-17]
docs/SmartRoadReflector_prototype.stl
202.0 x 202.0 x 165.6

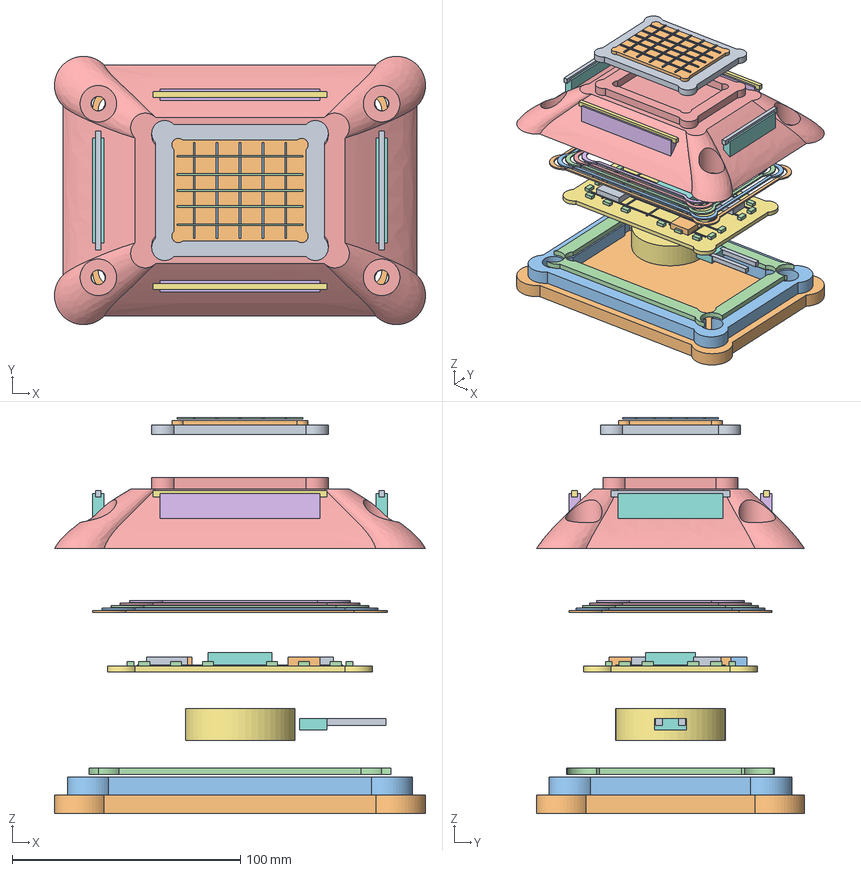
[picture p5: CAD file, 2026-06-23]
SmartRoadReflector_Rectangular_Objects.step
162.5 x 117.5 x 173.3 mm
_06_Rectangular_Solar_Panel_Print_Object
_05_Smooth_Pyramidal_Housing_With_Reflector_Indents_And_Screw_Holes_ Print_Object
_04_Antenna_Coil_Print_Object
_03_Populated_PCB_Print_Object
_02_Battery_Unit_Print_Object
_01_Rectangular_Sealed_Base_With_Screw_Holes_Print_Object

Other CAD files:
docs/SmartRoadReflector_Exploded_view_3D.dwg

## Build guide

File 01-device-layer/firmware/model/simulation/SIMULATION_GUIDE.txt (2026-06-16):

================================================================================
  ASPHALT VIBRATION MODEL — SIMULATION GUIDE
  Smart Road Reflector Project | Device Layer | Firmware Model
================================================================================

CONTENTS
--------
  1. Purpose and Scope
  2. Physical Model
     2.1 Asphalt Layer (SDOF System)
     2.2 Temperature-Dependent Modulus
     2.3 Equivalent Parameters
     2.4 Vehicle Load and Tire Force
     2.5 Sensor Array and Noise
     2.6 Vehicle Speed Estimation (Cross-Correlation)
     2.7 Event Detection (Windowed RMS)
     2.8 Spectrogram (STFT)
  3. Running the Simulation
  4. GUI Controls Reference
     4.1 Asphalt Section
     4.2 Vehicle Section
     4.3 Tire Load / Road Excitation Section
     4.4 Sensor Array & Detection Section
     4.5 Sensor / Simulation Section
     4.6 Buttons
  5. Plot Panels Reference
     5.1 Top-Left  — Tire Load at S1
     5.2 Top-Right — Asphalt Displacement at S1
     5.3 Mid-Left  — Sensor Array Acceleration
     5.4 Mid-Right — S1 Clean vs. Noisy Signal
     5.5 Bot-Left  — Spectrogram (STFT)
     5.6 Bot-Right — Event Detection (Windowed RMS)
  6. Results Panel
  7. Export Functions
     7.1 Save CSV
     7.2 Export JSON Dataset
  8. Typical Usage Workflows
  9. Known Limitations and Future Work
================================================================================

1. PURPOSE AND SCOPE
────────────────────
The simulation models the mechanical response of a road surface (asphalt layer)
to a passing vehicle and predicts what an embedded MEMS accelerometer (such as
the ADXL362) mounted inside a smart road reflector would measure.

The primary goals are:

  • Validate the physics of the road-sensor interaction before building hardware.
  • Calibrate detection thresholds and algorithm parameters for the firmware.
  • Validate the multi-sensor speed estimation algorithm used by the backend.
  • Generate labeled training datasets (JSON) for the vehicle classifier.

The simulation covers vehicle types ranging from motorcycles to 5-axle heavy
trucks and road temperatures from -20 °C to +55 °C.

================================================================================
2. PHYSICAL MODEL
================================================================================

2.1  ASPHALT LAYER — SINGLE-DEGREE-OF-FREEDOM (SDOF) SYSTEM
─────────────────────────────────────────────────────────────
The asphalt layer directly above the sensor is modeled as a single-degree-of-
freedom (SDOF) mass-spring-damper system:

         F(t)
          ↓
    ──────────────
    |    m_eq    |    ← equivalent mass of asphalt column
    |            |
    ╱╲  k_asph  ╱╲   ← asphalt stiffness (in series with subgrade)
    ──  c_eq   ──    ← viscous damping
    ╱╲  k_sub  ╱╲   ← subgrade stiffness
    ──────────────
         ↓ fixed ground

Equation of motion:

    m_eq · z̈  +  c_eq · ż  +  k_eq · z  =  F(t)

Where:
    z       = vertical displacement of the asphalt surface [m]
    z̈       = vertical acceleration of the surface [m/s²]
    F(t)    = tire force applied to the surface at time t [N]
    k_eq    = series combination of asphalt and subgrade stiffness [N/m]
    c_eq    = equivalent viscous damping [N·s/m]

The ODE is solved numerically using the Runge-Kutta RK45 integrator from
scipy.integrate.solve_ivp with tight tolerances (rtol=1e-7, atol=1e-9).

2.2  TEMPERATURE-DEPENDENT ASPHALT MODULUS
───────────────────────────────────────────
Asphalt behaves viscoelastically. Its storage modulus E' drops significantly
as temperature increases:

    Temperature [°C]  |  E' approximate value
    ──────────────────────────────────────────
        -20           |  22 GPa  (very stiff, winter)
        -10           |  16 GPa
          0           |  10 GPa
         20           |   4 GPa  (typical summer)
         40           |   0.9 GPa
         55           |   0.35 GPa  (very soft, hot pavement)

The model interpolates log10(E') linearly between these reference points. This
means that at 40 °C the surface is roughly 10× softer than at 0 °C, producing
much higher accelerations for the same vehicle load.

2.3  EQUIVALENT PARAMETERS
───────────────────────────
Starting from the asphalt geometry:

    A      = π · R²                           (effective contact area)

    m_eq   = ρ · h · A                        (mass of asphalt column)

    k_asph = E' · A / (h · (1 - ν²))         (asphalt layer stiffness)
                                              (corrected for Poisson effect)

    k_sub  = K_s · A                          (subgrade modulus → stiffness)

    k_eq   = (k_asph · k_sub) / (k_asph + k_sub)   (series combination)

    c_eq   = 2 · ζ · √(k_eq · m_eq)          (critical damping fraction)

    f_n    = (1 / 2π) · √(k_eq / m_eq)       (natural frequency)

Where:
    R   = effective influence radius [m]
    h   = asphalt thickness [m]
    ρ   = asphalt density [kg/m³]
    ν   = Poisson ratio (typically 0.35 for asphalt)
    K_s = subgrade modulus [N/m³]
    ζ   = viscous damping ratio (typically 0.10–0.25)

2.4  VEHICLE LOAD AND TIRE FORCE
──────────────────────────────────
The vehicle moves along the x-axis at constant speed. Each axle has two wheels
(left and right), and the number of axles is configurable.

  Total wheels = num_axles × (2 if opposite_wheels else 1)

Static force per wheel:

    F_static = (M · g) / total_wheels

Dynamic force multiplier (models suspension bounce and road roughness):

    multiplier = 1 + DLR · sin(2π · f_dyn · t)

Where:
    DLR   = Dynamic Load Ratio (e.g., 0.12 = ±12% variation)
    f_dyn = Dynamic load frequency [Hz] (typical: 2–15 Hz)

Spatial influence of each wheel on the sensor:

Each wheel contributes a force at the sensor position weighted by a 2D Gaussian
function of the horizontal distance between the wheel and the sensor:

    w(Δx, Δy) = exp( -(Δx² / 2σx²) - (Δy² / 2σy²) )

Where σx and σy are the influence spread radii. This models the fact that the
sensor "feels" a wheel most strongly when it is directly overhead, and the
effect fades with distance.

Total force on the sensor at time t:

    F(t) = Σ_wheels  F_wheel(t) · w(Δx, Δy)

Axle x-positions for a vehicle with n axles and spacing d:

    axle_i_x(t) = x_front(t) - i · d,   i = 0, 1, ..., n-1

2.5  SENSOR ARRAY AND NOISE MODEL
────────────────────────────────────
Up to 5 sensors can be simulated simultaneously at user-defined x positions
(e.g., S1 at 0 m, S2 at 4 m, S3 at 8 m).

For each sensor position the vehicle pass is re-simulated with the coordinate
frame shifted so that the vehicle fully traverses the sensor. All sensors share
the same simulation duration, so time offsets between sensors are physically
realistic.

ADXL362 Noise Model:

    σ_noise = noise_density [g/√Hz] × √(f_s / 2)

    Example: 175 µg/√Hz at 1000 Hz → σ = 175e-6 × √500 ≈ 3.9 mg RMS

Gaussian white noise with this standard deviation is added independently to
each sensor signal. This directly matches the ADXL362 datasheet specification.
The noise seed is fixed (seed=42) so results are reproducible.

2.6  VEHICLE SPEED ESTIMATION (CROSS-CORRELATION)
───────────────────────────────────────────────────
When the vehicle passes over two sensors separated by a known distance d [m],
its vibration signature arrives at S2 later than at S1 by a time lag τ [s].

The lag is found by maximizing the cross-correlation between the two signals:

    C(τ) = Σ_t  s1(t) · s2(t + τ)

The peak of |C(τ)| gives the best-estimate time delay τ_peak.

Estimated speed:

    v_est = d / |τ_peak|     [m/s]

This is the same algorithm that the backend will run on real sensor data. The
simulation output lets you tune the algorithm parameters (sensor spacing, sample
rate, noise level) and verify accuracy before deploying hardware.

Typical accuracy: ±5–15% depending on noise level and vehicle signature shape.

2.7  EVENT DETECTION (WINDOWED RMS)
─────────────────────────────────────
The firmware on the reflector node uses a windowed RMS + threshold algorithm
to decide whether a vehicle event is occurring.

Step 1 — Compute windowed RMS:
    RMS(t) = √( mean(x²) over a rolling window of W seconds )

Step 2 — Estimate baseline (background vibration):
    baseline = 15th percentile of RMS(t)

Step 3 — Threshold:
    threshold = baseline × multiplier

Step 4 — Event mask:
    event(t) = True  if RMS(t) > threshold

The 15th percentile baseline is robust to outliers and adapts automatically
to the ambient vibration level (e.g., high-traffic roads vs. quiet roads).

The simulation shows exactly which time windows would be flagged as vehicle
events with the current threshold setting, letting you calibrate this value
before burning it into firmware.

2.8  SPECTROGRAM (STFT)
─────────────────────────
The spectrogram shows how the frequency content of the S1 signal changes over
time using the Short-Time Fourier Transform (STFT).

A Hann window with 75% overlap is applied to successive segments of the signal.
The result is displayed as a color map where:

    X axis = time [s]
    Y axis = frequency [Hz], limited to 0–100 Hz
    Color  = power spectral density in dB

This view reveals the characteristic frequency sweep that occurs as the vehicle
approaches, passes directly over, and recedes from the sensor. It is more
informative than a single FFT because it shows temporal structure.

================================================================================
3. RUNNING THE SIMULATION
================================================================================

Requirements:
    Python 3.9+
    numpy, pandas, scipy, matplotlib, tkinter (included with Python)

Launch the interactive GUI:
    python asphalt_vibration_model.py

The simulation runs automatically on startup with default parameters.
Adjust any control and click "Update Simulation" to recompute.

The scipy RK45 solver with tight tolerances makes each run take roughly
0.5–3 seconds depending on vehicle speed, duration, and sample rate.

================================================================================
4. GUI CONTROLS REFERENCE
================================================================================

4.1  ASPHALT SECTION
─────────────────────

Temperature [°C]
    Range: -20 to +55 °C
    The pavement surface temperature. This is the single most impactful
    parameter: hot asphalt is ~10× softer than cold asphalt, which means
    much higher surface displacement and acceleration for the same vehicle.
    Use the temperature corresponding to the actual test conditions.

Thickness [cm]
    Range: 3 to 20 cm
    Thickness of the asphalt wearing course above the sensor. Typical roads
    have 6–12 cm. Thicker layers increase the equivalent mass and reduce
    stiffness slightly, lowering the natural frequency.

Effective Radius [m]
    Range: 0.10 to 1.00 m
    The radius of the circular asphalt area that is modeled as moving together
    with the sensor. This is an empirical parameter. Smaller values make the
    system lighter and stiffer (higher natural frequency). A value of 0.30–0.50 m
    is typical for a single-lane reflector installation.

Damping Ratio ζ
    Range: 0.01 to 0.60
    Fraction of critical damping. Asphalt is not a purely elastic material;
    it absorbs energy through viscous and hysteretic mechanisms.
    Typical values: 0.10–0.25 for normal asphalt at 20 °C.
    Higher temperatures increase damping. Higher damping suppresses resonance
    and reduces peak acceleration.

Subgrade Stiffness [MN/m³]
    Range: 20 to 300 MN/m³
    The modulus of reaction of the soil/base layer below the asphalt, also
    called the Winkler foundation modulus. Typical values:
        Soft soil (clay)  :  20–60 MN/m³
        Medium soil       :  60–150 MN/m³
        Gravel / rock     :  150–300 MN/m³
    The asphalt and subgrade stiffnesses are in series; the softer one
    dominates the total equivalent stiffness k_eq.

4.2  VEHICLE SECTION
─────────────────────

Vehicle Mass [kg]
    Range: 50 to 15,000 kg
    Total vehicle mass. Reference values:
        Motorcycle          :  150–350 kg
        Small car           :  900–1,400 kg
        SUV / pickup        :  1,600–2,800 kg
        Delivery truck      :  3,500–7,500 kg
        Heavy truck / semi  :  10,000–40,000 kg

Speed [km/h]
    Range: 2 to 120 km/h
    Vehicle travel speed. This controls how quickly each axle's load pulse
    sweeps over the sensor. Lower speed = longer pulse duration = more energy
    deposited. The speed is also what the cross-correlation algorithm will
    try to recover, so it is the ground-truth reference.

Number of Axles
    Range: 1 to 8
    Total number of axles. Combined with "Include opposite-side wheels",
    this determines the total number of wheel load points:
        Total wheels = num_axles × (2 if opposite_wheels else 1)
    Reference values:
        Motorcycle  : 2 axles, opposite OFF (1 wheel per axle)
        Car / SUV   : 2 axles, opposite ON  (4 wheels)
        Delivery    : 2–3 axles, opposite ON
        Semi-truck  : 5 axles, opposite ON  (10 wheels)

Axle Spacing [m]
    Range: 0.5 to 8.0 m
    Uniform distance between consecutive axles. In reality heavy trucks have
    non-uniform spacing (e.g., close tandem rear axles), but a uniform model
    is sufficient for class discrimination. Typical values:
        Car                 : 2.5–2.9 m
        Light truck         : 3.5–4.5 m
        Semi-truck (avg)    : 2.0–4.0 m per axle pair

Sensor Lateral Offset [m]
    Range: 0.0 to 3.0 m
    Horizontal (cross-lane) distance between the sensor and the nearest wheel
    path. A value of 0.0 means the sensor is directly in the wheel track.
    Road reflectors are typically installed on the lane edge marker at
    0.1–0.5 m from the wheel track. Increasing this value reduces the peak
    force received by the sensor.

Include opposite-side wheels (checkbox)
    When checked, wheels on both sides of the vehicle are modeled (left and
    right). When unchecked, only the near-side wheels are used. For a
    motorcycle or single-track vehicle, uncheck this option and set
    Number of Axles = 2.

4.3  TIRE LOAD / ROAD EXCITATION SECTION
──────────────────────────────────────────

Dynamic Load Ratio [%]
    Range: 0 to 50 %
    Amplitude of the sinusoidal dynamic load variation as a percentage of
    the static load. Caused by vehicle suspension oscillation and road
    surface roughness. A value of 12 % means the tire force oscillates
    between 88% and 112% of the static value.
    Typical values: 5–20 % for normal vehicles on smooth roads.
    Higher values represent damaged suspension or rough road surfaces.

Dynamic Load Frequency [Hz]
    Range: 1 to 40 Hz
    Frequency of the dynamic load oscillation. This corresponds to suspension
    bounce or unsprung mass resonance frequencies:
        Body bounce (sprung mass)    :  1–3 Hz
        Wheel hop (unsprung mass)    :  8–15 Hz
        Road surface waviness        :  varies with speed

Influence Sigma X [m]  (longitudinal spread)
    Range: 0.05 to 1.50 m
    Standard deviation of the Gaussian tire influence function along the
    direction of travel. Larger values mean the sensor "feels" the wheel
    over a longer stretch of the road (softer transition). This parameter
    controls the rise and fall time of each load pulse.

Influence Sigma Y [m]  (lateral spread)
    Range: 0.05 to 1.50 m
    Standard deviation of the Gaussian tire influence function in the
    cross-lane direction. Larger values mean the sensor receives significant
    force even from distant wheels. Should generally be ≤ lane width / 2.

4.4  SENSOR ARRAY & DETECTION SECTION
───────────────────────────────────────

Number of Sensors
    Range: 2 to 5
    How many sensor nodes to simulate in the array. In the Alpha Prototype
    the planned deployment is 3 sensors per lane (S1, S2, S3) at 4 m spacing.

Sensor Spacing [m]
    Range: 1.0 to 10.0 m
    Distance between consecutive sensors along the lane. This is the "d"
    in the speed estimation formula: v = d / τ. Larger spacing gives better
    speed resolution but requires the signal to be stable over a longer
    distance. Recommended: 3–6 m for road speeds 20–120 km/h.

Add ADXL362 noise (checkbox)
    When checked, Gaussian noise is added to each sensor signal independently
    using the noise density set below. This makes the simulated signals
    realistically "messy" and lets you test whether detection algorithms
    still work under real sensor conditions.

Noise Density [µg/√Hz]
    Range: 50 to 500 µg/√Hz
    Spectral noise density of the accelerometer. The ADXL362 datasheet
    specifies 175 µg/√Hz as the typical value. Higher values represent
    cheaper or lower-quality sensors. The RMS noise at a given sample rate is:
        σ = noise_density [g/√Hz] × √(sample_rate / 2)
    At 1000 Hz: σ ≈ 3.9 mg RMS with the ADXL362.

RMS Window [ms]
    Range: 10 to 500 ms
    Duration of the rolling window used to compute the windowed RMS for
    event detection. Shorter windows are more responsive but noisier.
    Longer windows are smoother but may miss short events (motorcycles).
    Recommended starting point: 50–150 ms.

Detection Threshold ×
    Range: 1.5 to 10.0
    Multiplier applied to the baseline RMS to set the event detection
    threshold. A value of 3.0 means: flag an event when the windowed RMS
    exceeds 3× the ambient background level.
    Lower values → more sensitive (may false-trigger on noise).
    Higher values → less sensitive (may miss light vehicles).
    Calibrate by observing the detection panel (bottom-right plot).

Vehicle Class
    Dropdown: small_vehicle, medium_vehicle, large_vehicle, heavy_vehicle,
              motorcycle
    Label applied to exported JSON datasets. Does not affect the simulation
    physics. Used to tag training data for the backend vehicle classifier.

4.5  SENSOR / SIMULATION SECTION
───────────────────────────────────

Housing Gain
    Range: 0.1 to 5.0
    A scalar multiplier applied to the computed surface acceleration to
    model the mechanical amplification (or attenuation) introduced by
    the reflector housing. A value of 1.0 means the sensor sees exactly
    the surface acceleration. Values > 1.0 model resonance of the housing
    structure. Values < 1.0 model acoustic decoupling or isolation.
    This parameter must be calibrated from physical measurements.

Sample Rate [Hz]
    Range: 100 to 3000 Hz
    The number of acceleration samples per second. Also sets the ODE
    time step (dt = 1/sample_rate). Higher rates improve accuracy and
    frequency resolution but increase simulation time.
    The ADXL362 supports up to 400 Hz in low-power mode and up to
    3200 Hz in full-power mode.
    Recommended for this simulation: 800–1000 Hz.

4.6  BUTTONS
─────────────

Update Simulation
    Recalculates the entire simulation with the current control values.
    Always click this after changing any parameter to refresh all plots
    and results. The simulation typically takes 0.5–3 seconds.

Save CSV
    Exports the S1 reference simulation data (time, force, displacement,
    velocity, acceleration) to:
        output/asphalt_vibration_simulation_gui.csv
    The output/ folder is created automatically if it does not exist.

Export JSON Dataset
    Exports a labeled multi-sensor dataset to:
        output/dataset_YYYYMMDD_HHMMSS.json
    The file contains: vehicle class label, true speed, estimated speed,
    asphalt temperature, sensor positions, and the complete time-series
    of acceleration for all sensors. This file can be fed directly to
    the backend machine learning classifier for training.

Expand All / Collapse All
    Toggle the visibility of all collapsible control sections to
    manage screen space.

================================================================================
5. PLOT PANELS REFERENCE
================================================================================

The plot area is organized as a 3 × 2 grid:

    ┌────────────────────┬────────────────────┐
    │ (0,0) Tire Load    │ (0,1) Displacement │
    ├────────────────────┼────────────────────┤
    │ (1,0) Array Accel  │ (1,1) Clean/Noisy  │
    ├────────────────────┼────────────────────┤
    │ (2,0) Spectrogram  │ (2,1) Event Detect │
    └────────────────────┴────────────────────┘

5.1  TOP-LEFT — Tire Load at S1 (reference)
────────────────────────────────────────────
    X axis: Time [s]
    Y axis: Force [N]

    Shows the total tire force F(t) applied to the sensor position as the
    vehicle passes. The curve is the sum of all wheel Gaussian contributions.

    What to look for:
    • Number of peaks = number of axles. Each axle produces a distinct
      force peak as it passes over the sensor.
    • Peak width = related to vehicle speed and Sigma X. Faster vehicles
      produce narrower, sharper peaks.
    • Ripple on each peak = the dynamic load oscillation (DLR).
    • The force returns to near-zero before and after the pass if the
      influence radii are small enough.

5.2  TOP-RIGHT — Asphalt Displacement at S1
─────────────────────────────────────────────
    X axis: Time [s]
    Y axis: Displacement [mm]

    Shows the vertical displacement z(t) of the asphalt surface computed
    by the ODE integrator.

    What to look for:
    • Peak displacement is typically in the range of 0.001–0.5 mm for
      common vehicles. Larger displacements indicate soft asphalt
      (high temperature) or heavy vehicles.
    • Residual oscillation after the vehicle passes indicates under-damping
      (low ζ). A well-damped system returns to zero quickly.
    • Multiple peaks corresponding to multiple axles.
    • Hot pavement (high T) → much larger displacement than cold pavement.

5.3  MID-LEFT — Sensor Array Acceleration
───────────────────────────────────────────
    X axis: Time [s]
    Y axis: Acceleration [g]
    Each sensor has a unique color; legend shows sensor ID and position.

    Shows the noisy accelerometer reading for all sensors in the array
    overlaid on the same time axis.

    What to look for:
    • Each sensor shows the same vehicle signature shifted in time. The
      horizontal offset between the peaks of adjacent sensors is the lag τ
      used for speed estimation.
    • With noise enabled, you can visually judge whether the signal peaks
      are still distinguishable above the noise floor.
    • For heavy vehicles the peaks are clearly separated. For light
      vehicles (motorcycle) the peaks may be buried in noise.

5.4  MID-RIGHT — S1 Clean vs. Noisy Signal
────────────────────────────────────────────
    X axis: Time [s]
    Y axis: Acceleration [g]
    Blue line = clean signal (no noise).
    Red line  = noisy signal (with ADXL362 noise added).

    Direct comparison of the true surface acceleration vs. what the
    sensor would actually output.

    What to look for:
    • If the red and blue lines are nearly indistinguishable, the signal-
      to-noise ratio (SNR) is good; the noise density or threshold
      multiplier may need to be increased to test realistic conditions.
    • If the red line is dominated by noise and the peaks are invisible,
      the SNR is too low for reliable detection. Options: reduce noise
      density, increase vehicle mass, increase sample rate, or use
      signal averaging.
    • Noise level is flat across all frequencies (white noise model).

5.5  BOTTOM-LEFT — Spectrogram (STFT)
───────────────────────────────────────
    X axis: Time [s]
    Y axis: Frequency [Hz], 0–100 Hz
    Color : Power spectral density [dB]  (brighter = more energy)

    The Short-Time Fourier Transform spectrogram of the S1 noisy signal.
    Unlike a single FFT, this shows how the frequency content changes
    over time during the vehicle pass.

    What to look for:
    • The system natural frequency f_n (shown in the Results panel) appears
      as a bright horizontal band when the system is excited near resonance.
    • As the vehicle approaches: broadband energy appears.
    • At peak excitation (vehicle directly over sensor): maximum brightness.
    • After the vehicle passes: energy fades, resonance may ring down
      at f_n if damping is low.
    • The dynamic load frequency appears as a persistent horizontal streak
      if DLR is significant.
    • Quiet periods (before/after vehicle) should show only the noise floor.

5.6  BOTTOM-RIGHT — Event Detection (Windowed RMS)
────────────────────────────────────────────────────
    X axis: Time [s]
    Y axis: RMS acceleration [g]
    Blue line  = windowed RMS of S1 signal
    Red dashed = detection threshold
    Red shaded = time windows flagged as vehicle event

    Visualization of the event detection algorithm as it would run on
    the real firmware.

    What to look for:
    • A well-calibrated detection shows the shaded region covering exactly
      the time when the vehicle was close to the sensor.
    • If the shaded region starts too early or ends too late: decrease the
      threshold multiplier or reduce the RMS window.
    • If no shading appears for a clearly visible vehicle: increase noise
      density (to raise the baseline), decrease the threshold multiplier,
      or use a shorter RMS window.
    • If background noise triggers false events: increase the multiplier.
    • The event duration (shown in the Results panel) can be used to
      estimate vehicle length: length ≈ speed × duration.

================================================================================
6. RESULTS PANEL
================================================================================

The panel below the buttons updates after every simulation run.

S1 Results
──────────
  Peak Force [N]      Maximum tire force seen by sensor S1.
  Peak Disp. [mm]     Maximum surface vertical displacement.
  Peak Accel. [g]     Maximum absolute acceleration (including noise if enabled).
  RMS Accel. [g]      Root-mean-square of the entire S1 signal.
  Dominant Freq. [Hz] Frequency of the highest FFT bin in the clean S1 signal.

Array
─────
  Est. Speed          Speed estimated from the S1→S2 cross-correlation lag.
                      Shows estimated value in m/s and km/h, and the raw lag in ms.
                      Compare with the "Speed [km/h]" control for accuracy.
  Event               Detection result: time range and duration in ms.
                      "No event detected" appears when the RMS never exceeds
                      the threshold.

Model
─────
  Asphalt E' [GPa]    Storage modulus at the current temperature.
  Natural Freq. [Hz]  SDOF natural frequency f_n = (1/2π)√(k_eq/m_eq).
  k_eq [N/m]          Equivalent stiffness (series of asphalt + subgrade).
  c_eq [N·s/m]        Equivalent viscous damping coefficient.

================================================================================
7. EXPORT FUNCTIONS
================================================================================

7.1  SAVE CSV
──────────────
Output: output/asphalt_vibration_simulation_gui.csv

Columns:
    time_s           Simulation time [s]
    force_n          Tire force at sensor [N]
    displacement_m   Surface vertical displacement [m]
    displacement_mm  Surface vertical displacement [mm]
    velocity_m_s     Surface vertical velocity [m/s]
    acceleration_m_s2 Surface acceleration [m/s²]
    acceleration_g   Surface acceleration [g]

This file contains only the S1 reference simulation (no noise).
Useful for plotting in external tools or comparing with measured data.

7.2  EXPORT JSON DATASET
─────────────────────────
Output: output/dataset_YYYYMMDD_HHMMSS.json

Schema:
    generated_at          ISO 8601 UTC timestamp
    vehicle_class         Label from the Vehicle Class dropdown
    vehicle_mass_kg       Vehicle mass [kg]
    num_axles             Number of axles
    speed_true_m_s        Ground truth speed [m/s]
    speed_true_kmh        Ground truth speed [km/h]
    speed_estimated_m_s   Speed estimated by cross-correlation [m/s]
    asphalt_temperature_c Pavement temperature [°C]
    sensors[]             List of { sensor_id, x_m } for each sensor
    samples[]             List of { sensor_id, time_s, acceleration_g, force_n }

Use this file to build training datasets for the backend vehicle classifier.
Generate one file per vehicle configuration and label combination. Multiple
files can be concatenated or fed to a batch training script.

================================================================================
8. TYPICAL USAGE WORKFLOWS
================================================================================

WORKFLOW A — Calibrate detection threshold for a specific road and sensor
──────────────────────────────────────────────────────────────────────────
  1. Set Temperature and Subgrade Stiffness to match the target road.
  2. Set Vehicle Mass, Speed, and Axles for the target vehicle class.
  3. Enable noise and set Noise Density to 175 µg/√Hz (ADXL362 default).
  4. Adjust "Detection Threshold ×" until the shaded event region in the
     bottom-right plot covers exactly the vehicle pass time.
  5. Note the threshold value — use it as the initial firmware parameter.
  6. Repeat with a lighter vehicle (motorcycle) to ensure the threshold
     does not miss it.

WORKFLOW B — Validate speed estimation accuracy
────────────────────────────────────────────────
  1. Set Number of Sensors = 3, Sensor Spacing = 4.0 m.
  2. Set vehicle speed to a known value (e.g., 60 km/h = 16.67 m/s).
  3. Enable noise at 175 µg/√Hz.
  4. Run simulation and check "Est. Speed" in the Results panel.
  5. Try different noise levels, vehicle masses, and speeds to map the
     accuracy of the cross-correlation estimator.
  6. The accuracy should be ±5–15% under typical conditions.

WORKFLOW C — Generate a training dataset
──────────────────────────────────────────
  1. Choose a vehicle configuration (e.g., heavy_vehicle: 18000 kg, 3 axles).
  2. Set a realistic temperature range and run for several temperatures.
  3. After each run, click "Export JSON Dataset".
  4. Change the Vehicle Class label and repeat for each class.
  5. Vary speed and mass within each class to create diversity.
  6. Use the generated JSON files to train the backend classifier.

WORKFLOW D — Inspect resonance behavior
─────────────────────────────────────────
  1. Set Damping Ratio ζ = 0.05 (lightly damped).
  2. Set a slow vehicle speed (5 km/h) to deliver a slow-moving load.
  3. Observe the displacement plot: residual oscillation at f_n after the pass.
  4. Check the spectrogram for the resonant frequency band.
  5. Gradually increase ζ and observe how the ringing decreases.

================================================================================
9. KNOWN LIMITATIONS AND FUTURE WORK
================================================================================

Current limitations:

  1. SDOF model
     The asphalt is modeled as a single degree of freedom. A more accurate
     model would use a layered elastic half-space (Boussinesq or FEM), but
     this is computationally too expensive for real-time interactive use.

  2. Flat road profile (no ISO 8608 roughness)
     The road surface is assumed perfectly flat. Real roads have stochastic
     roughness described by ISO 8608 classes A–H. Adding random roughness
     would make background vibration levels more realistic and improve
     detection threshold calibration.

  3. No quarter-car vehicle dynamics
     The vehicle suspension is approximated by the dynamic load multiplier
     (DLR). A proper quarter-car model with sprung/unsprung mass and tire
     stiffness would produce more accurate force time histories, especially
     the secondary suspension bounce peak at 1–3 Hz.

  4. Uniform axle load distribution
     All axles carry equal load. Real heavy trucks have unequal axle loads
     (front axle typically carries less than rear tandem axles).

  5. 2D influence model
     The Gaussian influence function assumes the sensor is at y = 0. The
     vehicle lateral position is fixed; lane weaving is not modeled.

  6. Constant speed
     Vehicle acceleration and deceleration are not modeled.

  7. No temperature gradient
     Temperature is uniform through the asphalt layer; in reality the top
     surface is hotter than the bottom on a sunny day.

Planned improvements:

  • ISO 8608 random road roughness generator
  • Quarter-car (2-DOF) vehicle model
  • Per-axle load distribution profile
  • Batch simulation mode for dataset generation without GUI
  • Live comparison with real sensor data from CSV import

================================================================================
END OF DOCUMENT
================================================================================

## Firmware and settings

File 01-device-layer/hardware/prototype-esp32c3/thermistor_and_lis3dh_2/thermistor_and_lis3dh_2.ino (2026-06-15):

#include <Arduino.h>
#include <Wire.h>
#include <math.h>

#include <Adafruit_LIS3DH.h>
#include <Adafruit_Sensor.h>

// -------------------- Pins --------------------
#define NTC_ADC_PIN      3
#define NTC_POWER_PIN    2

#define I2C_SDA_PIN      0
#define I2C_SCL_PIN      1

#define PIEZO_ADC_PIN    4

// -------------------- NTC Parameters --------------------
const float SERIES_RESISTOR = 100000.0;
const float NOMINAL_RESISTANCE = 100000.0;
const float NOMINAL_TEMPERATURE = 25.0;
const float BETA_COEFFICIENT = 3950.0;

// Use your measured voltage from the GPIO power pin.
const float NTC_SUPPLY_VOLTAGE = 3.13;

// -------------------- Timing --------------------
const uint32_t SENSOR_INTERVAL_MS = 5;       // 200 Hz target
const uint32_t PRINT_INTERVAL_MS  = 20;      // 50 Hz serial output
const uint32_t NTC_INTERVAL_MS    = 1000;    // NTC every 1 second

uint32_t lastSensorReadMs = 0;
uint32_t lastPrintMs = 0;
uint32_t lastNTCReadMs = 0;
uint32_t lastPiezoPeakResetMs = 0;

float lastTemperatureC = NAN;

// -------------------- LIS3DH --------------------
Adafruit_LIS3DH lis = Adafruit_LIS3DH();

// Gravity / vibration processing
float gravityMagEstimate = 9.81;
float peakDynamic = 0.0;
const float GRAVITY_ALPHA = 0.01;

// -------------------- Piezo Processing --------------------
float piezoBaselineMv = 0.0;
float piezoSignalMv = 0.0;
float piezoPeakMv = 0.0;

// Adjust after testing.
// Start low, then tune based on real noise.
const float PIEZO_EVENT_THRESHOLD_MV = 80.0;

// Smaller alpha = slower baseline tracking.
// This helps remove slow drift and keep fast impacts.
const float PIEZO_BASELINE_ALPHA = 0.02;

float calculateNTCTemperatureC(float resistance)
{
  float steinhart = resistance / NOMINAL_RESISTANCE;
  steinhart = log(steinhart);
  steinhart /= BETA_COEFFICIENT;
  steinhart += 1.0 / (NOMINAL_TEMPERATURE + 273.15);
  steinhart = 1.0 / steinhart;
  steinhart -= 273.15;

  return steinhart;
}

float readNTCTemperatureC()
{
  pinMode(NTC_POWER_PIN, OUTPUT);
  digitalWrite(NTC_POWER_PIN, HIGH);

  delay(20);

  const int samples = 10;
  uint32_t mvSum = 0;

  for (int i = 0; i < samples; i++) {
    mvSum += analogReadMilliVolts(NTC_ADC_PIN);
    delay(2);
  }

  float voltage = (mvSum / (float)samples) / 1000.0;

  digitalWrite(NTC_POWER_PIN, LOW);
  pinMode(NTC_POWER_PIN, INPUT);

  if (voltage <= 0.01 || voltage >= NTC_SUPPLY_VOLTAGE - 0.01) {
    return NAN;
  }

  float ntcResistance = SERIES_RESISTOR * (voltage / (NTC_SUPPLY_VOLTAGE - voltage));
  return calculateNTCTemperatureC(ntcResistance);
}

void setupLIS3DH()
{
  Wire.begin(I2C_SDA_PIN, I2C_SCL_PIN);

  if (!lis.begin(0x18)) {
    if (!lis.begin(0x19)) {
      Serial.println("ERROR,LIS3DH_NOT_FOUND");
      while (1) {
        delay(1000);
      }
    }
  }

  // Use ±2g for small vibration tests.
  // Later, for vehicle impact testing, try ±8g or ±16g.
  lis.setRange(LIS3DH_RANGE_2_G);

  // Fast enough for vibration testing.
  lis.setDataRate(LIS3DH_DATARATE_400_HZ);
}

float readPiezoMv()
{
  const int samples = 4;
  uint32_t mvSum = 0;

  for (int i = 0; i < samples; i++) {
    mvSum += analogReadMilliVolts(PIEZO_ADC_PIN);
  }

  return mvSum / (float)samples;
}

void setup()
{
  delay(3000);

  Serial.begin(115200);
  delay(1000);

  analogReadResolution(12);

  analogSetPinAttenuation(NTC_ADC_PIN, ADC_11db);
  analogSetPinAttenuation(PIEZO_ADC_PIN, ADC_11db);

  pinMode(NTC_POWER_PIN, INPUT);
  pinMode(PIEZO_ADC_PIN, INPUT);

  setupLIS3DH();

  // Initialize piezo baseline
  delay(100);
  piezoBaselineMv = readPiezoMv();

  Serial.println("time_ms,temp_c,ax,ay,az,mag,dynamic_mag,peak_dynamic,piezo_mv,piezo_signal_mv,piezo_peak_mv,piezo_event");
}

void loop()
{
  uint32_t nowMs = millis();

  if (nowMs - lastNTCReadMs >= NTC_INTERVAL_MS) {
    lastNTCReadMs = nowMs;
    lastTemperatureC = readNTCTemperatureC();
  }

  if (nowMs - lastSensorReadMs >= SENSOR_INTERVAL_MS) {
    lastSensorReadMs = nowMs;

    // -------------------- LIS3DH Read --------------------
    sensors_event_t event;
    lis.getEvent(&event);

    float ax = event.acceleration.x;
    float ay = event.acceleration.y;
    float az = event.acceleration.z;

    float mag = sqrt((ax * ax) + (ay * ay) + (az * az));

    gravityMagEstimate =
      (1.0 - GRAVITY_ALPHA) * gravityMagEstimate +
      GRAVITY_ALPHA * mag;

    float dynamicMag = fabs(mag - gravityMagEstimate);

    if (dynamicMag > peakDynamic) {
      peakDynamic = dynamicMag;
    }

    // -------------------- Piezo Read --------------------
    float piezoMv = readPiezoMv();

    piezoBaselineMv =
      (1.0 - PIEZO_BASELINE_ALPHA) * piezoBaselineMv +
      PIEZO_BASELINE_ALPHA * piezoMv;

    piezoSignalMv = fabs(piezoMv - piezoBaselineMv);

    if (piezoSignalMv > piezoPeakMv) {
      piezoPeakMv = piezoSignalMv;
    }

    bool piezoEvent = piezoSignalMv >= PIEZO_EVENT_THRESHOLD_MV;

    // -------------------- Print CSV --------------------
    if (nowMs - lastPrintMs >= PRINT_INTERVAL_MS) {
      lastPrintMs = nowMs;

      Serial.print(nowMs);
      Serial.print(",");

      if (isnan(lastTemperatureC)) {
        Serial.print("nan");
      } else {
        Serial.print(lastTemperatureC, 2);
      }

      Serial.print(",");
      Serial.print(ax, 4);
      Serial.print(",");
      Serial.print(ay, 4);
      Serial.print(",");
      Serial.print(az, 4);
      Serial.print(",");
      Serial.print(mag, 4);
      Serial.print(",");
      Serial.print(dynamicMag, 4);
      Serial.print(",");
      Serial.print(peakDynamic, 4);
      Serial.print(",");
      Serial.print(piezoMv, 2);
      Serial.print(",");
      Serial.print(piezoSignalMv, 2);
      Serial.print(",");
      Serial.print(piezoPeakMv, 2);
      Serial.print(",");
      Serial.println(piezoEvent ? 1 : 0);
    }

    // Reset peaks every second
    if (nowMs - lastPiezoPeakResetMs >= 1000) {
      lastPiezoPeakResetMs = nowMs;
      peakDynamic = 0.0;
      piezoPeakMv = 0.0;
    }
  }
}

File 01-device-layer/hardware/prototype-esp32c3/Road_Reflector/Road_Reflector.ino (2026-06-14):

#include <Arduino.h>
#include <math.h>

#define NTC_ADC_PIN 4

const float SERIES_RESISTOR = 100000.0;      // 100k fixed resistor
const float NOMINAL_RESISTANCE = 100000.0;   // 100k NTC at 25°C
const float NOMINAL_TEMPERATURE = 25.0;      // 25°C
const float BETA_COEFFICIENT = 3950.0;
const float ADC_MAX = 4095.0;
const float VCC = 3.3;

float calculateTemperatureC(float resistance)
{
  float steinhart = resistance / NOMINAL_RESISTANCE;
  steinhart = log(steinhart);
  steinhart /= BETA_COEFFICIENT;
  steinhart += 1.0 / (NOMINAL_TEMPERATURE + 273.15);
  steinhart = 1.0 / steinhart;
  steinhart -= 273.15;

  return steinhart;
}

void setup()
{
  delay(3000);

  Serial.begin(115200);
  delay(1000);

  analogReadResolution(12);
  analogSetPinAttenuation(NTC_ADC_PIN, ADC_11db);

  Serial.println();
  Serial.println("ESP32-C3 NTC debug test");
}

void loop()
{
  const int samples = 30;
  uint32_t adcSum = 0;

  for (int i = 0; i < samples; i++) {
    adcSum += analogRead(NTC_ADC_PIN);
    delay(5);
  }

  float adcValue = adcSum / (float)samples;
  float voltage = (adcValue / ADC_MAX) * VCC;

  // Use this if your wiring is:
  // 3.3V -> 100k resistor -> ADC -> NTC -> GND
  float ntcResistance = SERIES_RESISTOR * (voltage / (VCC - voltage));

  float temperatureC = calculateTemperatureC(ntcResistance);

  Serial.println("-----------------------------");
  Serial.print("ADC raw: ");
  Serial.println(adcValue);

  Serial.print("Voltage: ");
  Serial.print(voltage, 3);
  Serial.println(" V");

  Serial.print("NTC resistance: ");
  Serial.print(ntcResistance, 0);
  Serial.println(" ohms");

  Serial.print("Temperature: ");
  Serial.print(temperatureC, 2);
  Serial.println(" C");

  delay(1000);
}

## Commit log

2026-06-14 first version of workable code with thermistor and accel
2026-06-14 Add serial_debug_reader script for reading data from serial port
    - Implemented a new Python script to read and display data from a specified serial port.
    - Added command-line arguments for port selection and baud rate configuration.
    - Included error handling for serial data reading and graceful shutdown on interrupt.
    [plot_sensors_live.py, thermistor_and_lis3dh_2.ino]
2026-06-15 Enhance sensor data processing and visualization: add piezo sensor support, update data parsing, and improve plot layout
2026-06-15 Add commands documentation and new presentation file
    - Created a new commands.txt file containing instructions to run the sensor plotting script.
    - Added a new PowerPoint presentation file for the Smart Reflector project.
2026-06-15 Add tools for live sensor data plotting and documentation
    - Introduced `plot_sensors_live.py` for real-time visualization of sensor data from the ESP32-C3 prototype.
    - Added `README.md` in the tools directory to provide usage instructions for the live serial plotter.
    - Included a new PowerPoint presentation file `SmartReflector 1.pptx` for documentation purposes.
    [Road Reflector BOM.xlsx]
2026-06-15 Add thermal management documentation and prototype code for smart road reflector
    - Created a comprehensive document detailing thermal management and structural housing for the SmartReflect platform, addressing key engineering problems, functional requirements, and candidate housing options.
    - Added commands file for running live sensor data plotting.
    - Implemented a serial debug reader script for reading and printing serial data from the ESP32-C3.
    - Developed the main Arduino sketch for the thermistor and LIS3DH sensor integration, including temperature and vibration processing.
    - Introduced a recommended stack file outlining device components, connectivity, network server, message layer, ba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
    [thermistor_and_lis3dh_2.ino]
2026-06-15 feat: add web dashboard for Smart Road Reflector with 3D visualization and telemetry
    - Created a new web dashboard structure with HTML, CSS, and JavaScript files.
    - Implemented a responsive layout with KPIs, live event feed, and sensor status.
    - Integrated Three.js for real-time 3D visualization of road conditions.
    - Added WebSocket support for live telemetry and vehicle events.
    - Developed a simulation feeder to generate synthetic telemetry and vehicle events for testing.
    - Enhanced README documentation to include details about the new dashboard and its components.
2026-06-16 Refactor code structure for improved readability and maintainability
    [asphalt_vibration_simulation.csv]
2026-06-17 Add files via upload
    Drawing files
    [SmartRoadReflector_Exploded_view_3D.dwg, SmartRoadReflector_prototype.stl]
2026-06-23 Add files via upload
    Step files for prototype drawings
    [SmartRoadReflector_6a.step, SmartRoadReflector_Rectangular_Objects.step]
